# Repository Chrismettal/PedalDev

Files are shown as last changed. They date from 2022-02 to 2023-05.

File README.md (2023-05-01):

# PedalDev <!-- omit in toc -->





This is a convenient system for quickly creating stompboxes, as well as a collection of designs made with this system.

The design is split into two boards, a lower and an upper one. The lower PCB handles all of the I/O, switching, and power stuff, while the upper one focuses on the individual effect. The two boards plug together and fit neatly inside a commonly used Hammond 1590B. For each finished design there is also a PCB frontpanel so I don't have to deal with any actual design work and can just hide my designs behind technical looking stuff. The actual boards take full advantage of modern SMD components for optimal space usage.

All designs build up from the same template to allow rapid creation of new designs as well as saving time on recurring steps. There are even various protoboard variants of the upper PCB fitting the same template, to make boutique one-off designs more convenient and robust. For every design you will find the full KiCAD project including schematic and production files like **BOM, Gerbers and PCBA place files** in their respective project folders. (`/pcb/*`)

For easy mechanical manufacturing a 3D printable drilling template is provided. There is also a 3D printable design of the full stompbox similar to the 1590B with all ports "predrilled". A plastic case is not super recommended though and should only be used for quick testing. Conductive spray paint as shielding on the inside is also recommended when using the 3D printed case. (`/3d/*`)

Parts marked with ":construction:" are work in progress and not fully verified yet.

---

Individual boards, predrilled cases as well as kits will be stocked at Tindie!



**If you like my work please consider [supporting my caffeine addiction](https://github.com/Chrismettal#donations)!**

## Table of contents <!-- omit in toc -->

- [Specific Designs](#specific-designs)
  - [404 (:sheep: Ibanez Tubescreamer)](#404-sheep-ibanez-tubescreamer)
  - [YOU WHAT?! (:sheep: emma electronic PisdiYAUwot)](#you-what-sheep-emma-electronic-pisdiyauwot)
  - [:construction: TOP (:sheep: OKKO Dominator)](#construction-top-sheep-okko-dominator)
- [Common PCBs](#common-pcbs)
  - [Lower](#lower)
  - [:construction: Lower Smart](#construction-lower-smart)
- [Protoboards](#protoboards)
  - [Proto Simple](#proto-simple)
- [Designing your own effects](#designing-your-own-effects)
- [Building guide](#building-guide)
  - [Case](#case)
  - [Electronics](#electronics)
- [Sources](#sources)
- [Tools](#tools)
- [Donations](#donations)
- [License](#license)

## Specific Designs

While there aren't many specific designs right now, they will be created faster now that the system is proven working. There is a wide range of devices in the works, from high gain distortions over reverbs to new, experimental stuff.

### 404 (:sheep: Ibanez Tubescreamer)

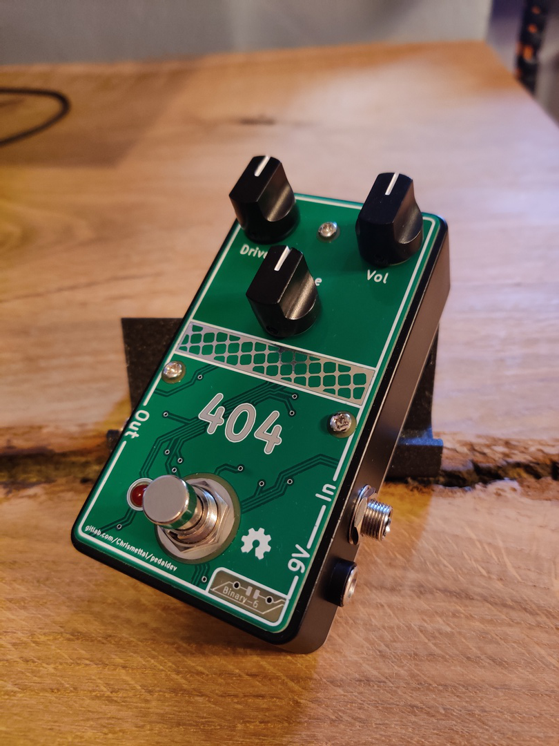
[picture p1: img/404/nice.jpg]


Based on the popular Tubescreamer this is obviously the first design to be done in this system.

Nothing crazy here, only `D1-3` feature a dual footprint to put in your favourite clipping diodes.

There are two jumpers that need to be set when building this board. `JP1` does not really do anything with the sound but chooses a filter to be sent to ground or to bias voltage as some schematics have it either way. `JP2` however allows choosing betweeen symmetrical or assymetrical clipping.

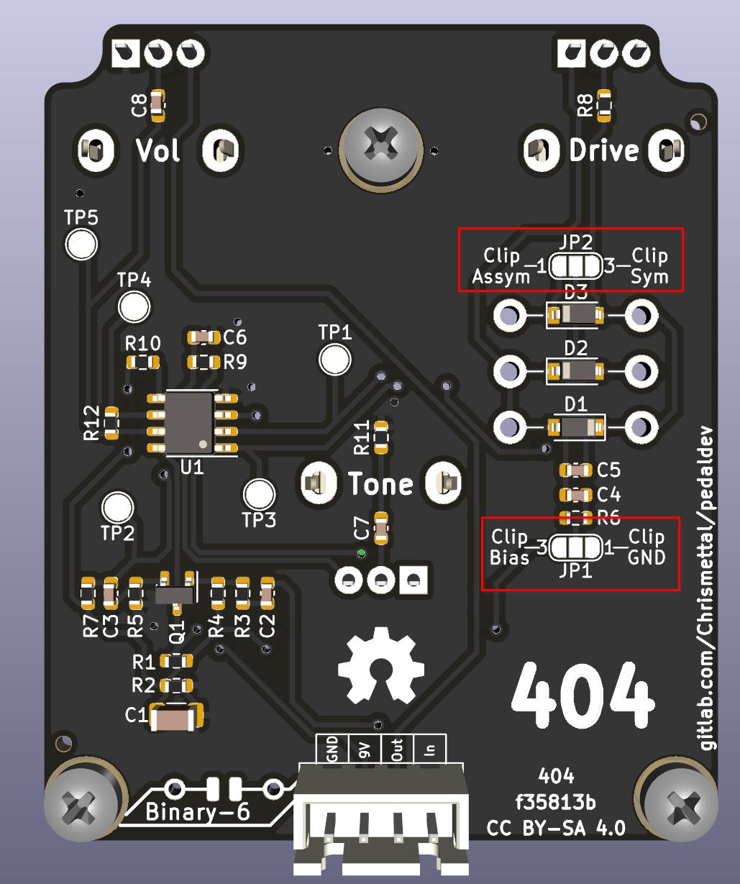
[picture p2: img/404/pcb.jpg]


### YOU WHAT?! (:sheep: emma electronic PisdiYAUwot)

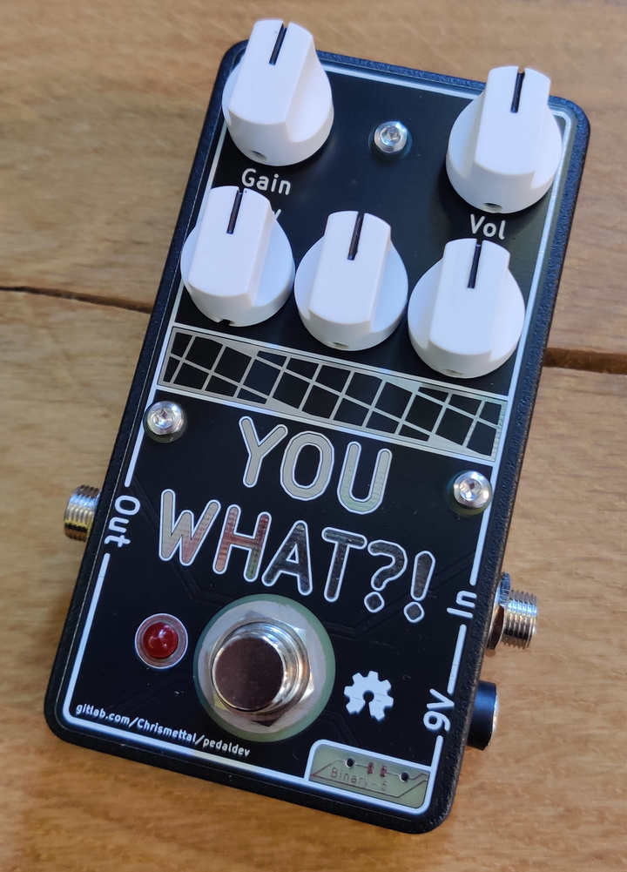
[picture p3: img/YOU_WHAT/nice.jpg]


Very cheap in parts but incredibly tight high gain distortion with lots of attack.

### :construction: TOP (:sheep: OKKO Dominator)

:construction: :construction: :construction: **Work in progress** :construction: :construction: :construction:

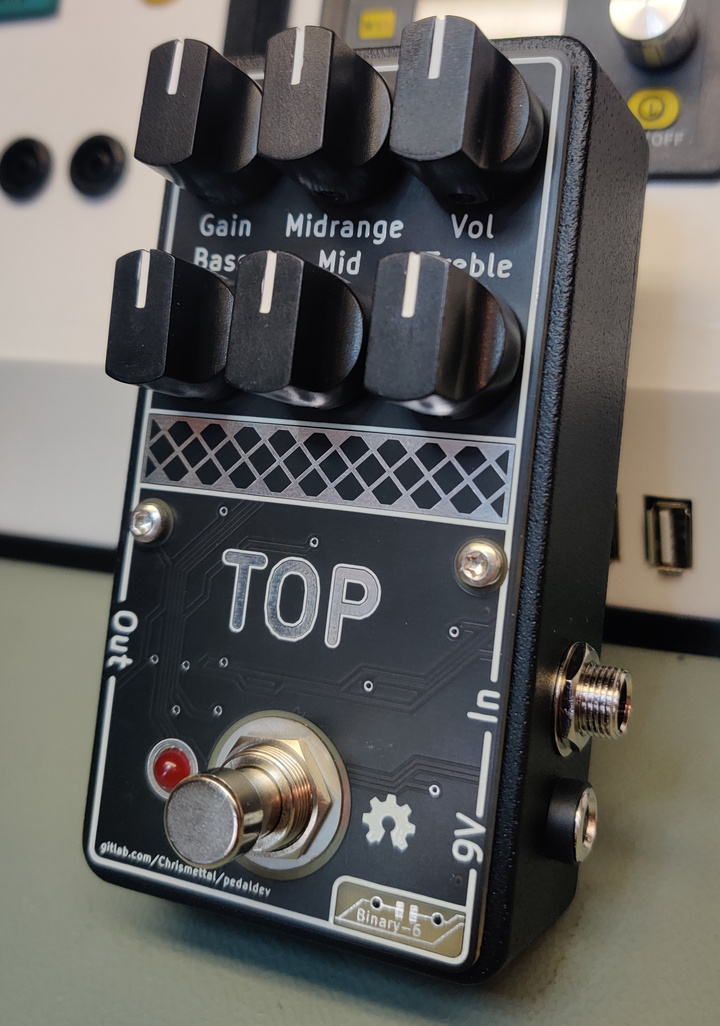
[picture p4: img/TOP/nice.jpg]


Based on schematic by Saruman [found here](https://www.freestompboxes.org/viewtopic.php?t=12031&hilit=c6).

First PCB version `f35813b` was broken is currently being debugged. 4 Pins on `TL074` were swapped, `ICL7660` does not work when `BOOST` mode is set (But **`ICL7660S`** does..), and input stage sounds super starved, more like a bassy fuzz than a distortion. Simulation seems to confirm this so confidence in schematic is low. Currently getting hold of an original Dominator for schematic comparison.

Two jumpers on board revision `f35813b` are for debugging the power stage around the `7660` but will probably be removed or clarified on the fixed revision

## Common PCBs

### Lower

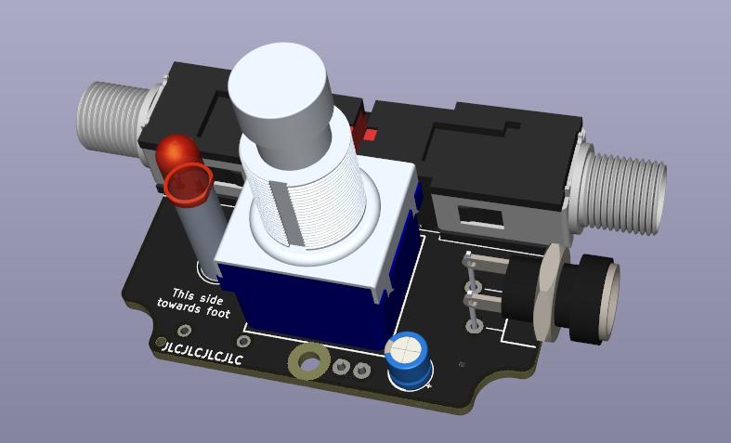
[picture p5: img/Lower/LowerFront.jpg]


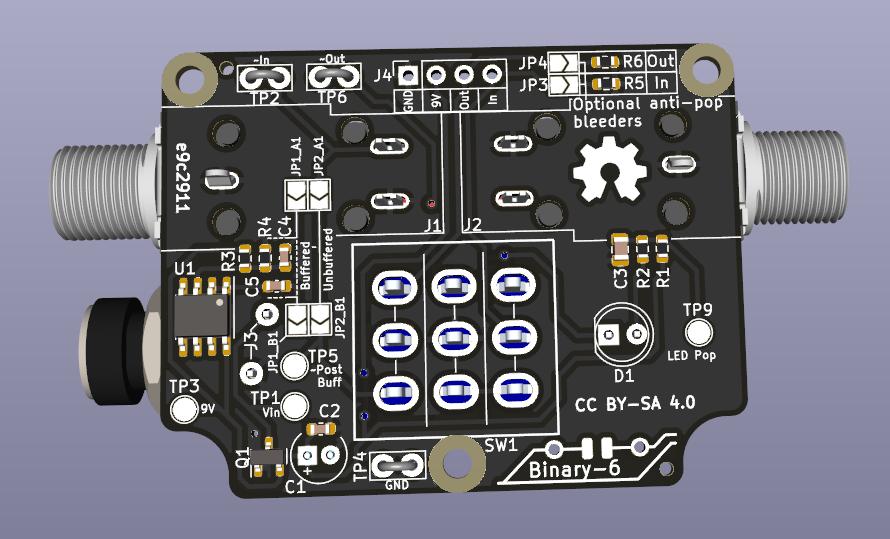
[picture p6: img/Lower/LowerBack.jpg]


The lower PCB consists of the bypass footswitch with a status LED, input and output jacks as well as power input, filtering and FET based reverse polarity protection.

The Input/Output jacks are called `PJ-602B`. These are not available via LCSC sadly, but can be found all over Aliexpress. 

Additionally an optional TL07X based buffer can be enabled via two jumpers. This was only added because the PCB had enough room for it and it can save room on the pedalboard instead of adding a separate buffer box. The buffer parts do NOT NEED to be populated if you intend never to use them. **Either `JP1_A1` and `JP1_B1` or `JP2_A1` and `JP2_B1` need to be set for signal to be passed through**.

The LED is driven through a simple "anti pop" filter and two optional anti-pop bleeders can be enabled via `JP3` and `JP4` to bleed any input/output caps on the connected upper board if neccessary.

Test hooks and pads are sprinkled on interesting signals for effect development and debugging.

> :bulb: Hint: 
> 
> While this system is intended to be used with one lower PCB and one upper PCB fitting together, it might be convenient to just use the lower PCB even if you do not intend to use an actual effect from this system. Doing so greatly reduces the amount of free form wiring and frees up some space on your actual effect PCB.

### :construction: Lower Smart

:construction: :construction: :construction: **Work in progress** :construction: :construction: :construction:

Same as `Lower`, but instead of a true bypass 3PDT Switch it features a microcontroller to turn your effect on and off either in momentary or latching mode. To show the mode it's currently on, it uses a bicolor LED.

On initial bootup, the device will be in latching mode. Pressing the button will toggle the effect on and off. The :construction: colored LED will be on as long as the effect is on in toggle mode. 
Holding the button down for 9 seconds, both LEDs will start blinking, signaling that a mode change is imminent. Holding the button for one more second, the device will switch into momentary mode.
In momentary mode, the effect will only be on while the button is held. While the effect is on, a :construction: colored LED will be on in momentary mode.
Switching back to toggle mode works the same way, by holding down the button long enough.

## Protoboards

### Proto Simple

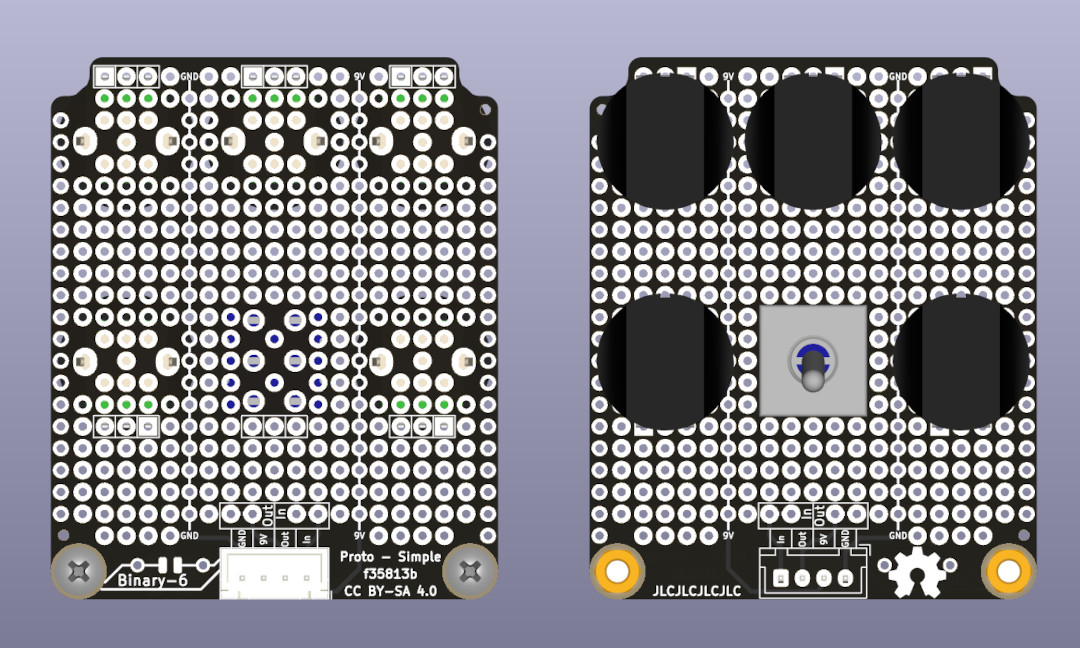
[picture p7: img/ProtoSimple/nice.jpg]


This is a simple protoboard to use as an "upper" board, allowing for up to 6 pots, or 5 pots with one DPDT print switch.
It features 9V and GND power rails straight through the design to allow for easy power distribution

While it does not allow for the density of SMD components it can certainly fit a lot of designs.

## Designing your own effects

I would love to merge your designs using this system into this repo!

To design your own effect PCB, create a copy of the `UpperRaw` KiCAD project for the actual effect, and `FrontRaw` for a PCB frontpanel design. `UpperRaw` includes a collection of frequently used parts in the schematic, set up with LCSC part numbers etc. It would be great if you add LCSC part numbers to all parts used in your design as well. After merging I will recreate the production files to the same parameters as the already created designs so don't worry about that.

---

## Building guide

As the system tries to use the little space in the 1590B as efficient as possible, the actual build can be quite tight. There is a set order of steps that should be taken to make the build as quick and easy as possible.

The whole system is designed so the PCBs can be ordered from JLCPCB mostly populated, so only very little hand soldering is involved. If you order the boards finished you will mostly have to solder only the through hole components, but for some rare components that JLCPCB doesn't populate, it might be neccessary to solder some SMD components manually. SMD components go down to `0603` for passives, and `SOIC-*` / `SOT-*` for actives, which is still hand solderable without too much trouble. A hot air solder station is highly recommended though.

<details>
  <summary markdown="span">Building guide, click to expand</summary>

### Case

If you have access to a 3D printer (or to my [Tindie Shop](https://www.tindie.com/stores/binary-6/)), there is a printable drill guide available. Otherwise, there will be a techdraw sheet with all the dimensions. At the [shop](https://www.tindie.com/stores/binary-6/) you will also find predrilled, black cases directly manufactured by Hammond.

All models are compatible with the same drill layout. Holes not required for a specific board will be hidden by the front plate, so the fully stacked 6 controls variant works for every model.

1. Put the case in the drill guide and use a center punch to mark out all the holes to be drilled

2. Pre-drill all marked holes with a `3mm drill bit` (The smallest size used on the device)

3. Drill out all the holes to the sizes marked on the drill guide. Note that the holes are all 0.5mm - 1mm larger than they need to be to make alignment of the frontpanel easier

4. If you want to paint the case, this would be the step to do it. I clean the case with rubbing alcohol, prime and paint, while only focusing on the sides of the case as I will hide the top underneath the frontpanels.

### Electronics

1. Some boards require several components to be mounted manually (Check their individual [documentation](#specific-designs)). These will include through hole parts or not easily available active parts for example. In this case, the OpAmp and input stage transistors, as well as connectors need to be placed manually. Note that the pots and switches are NOT placed at this stage!

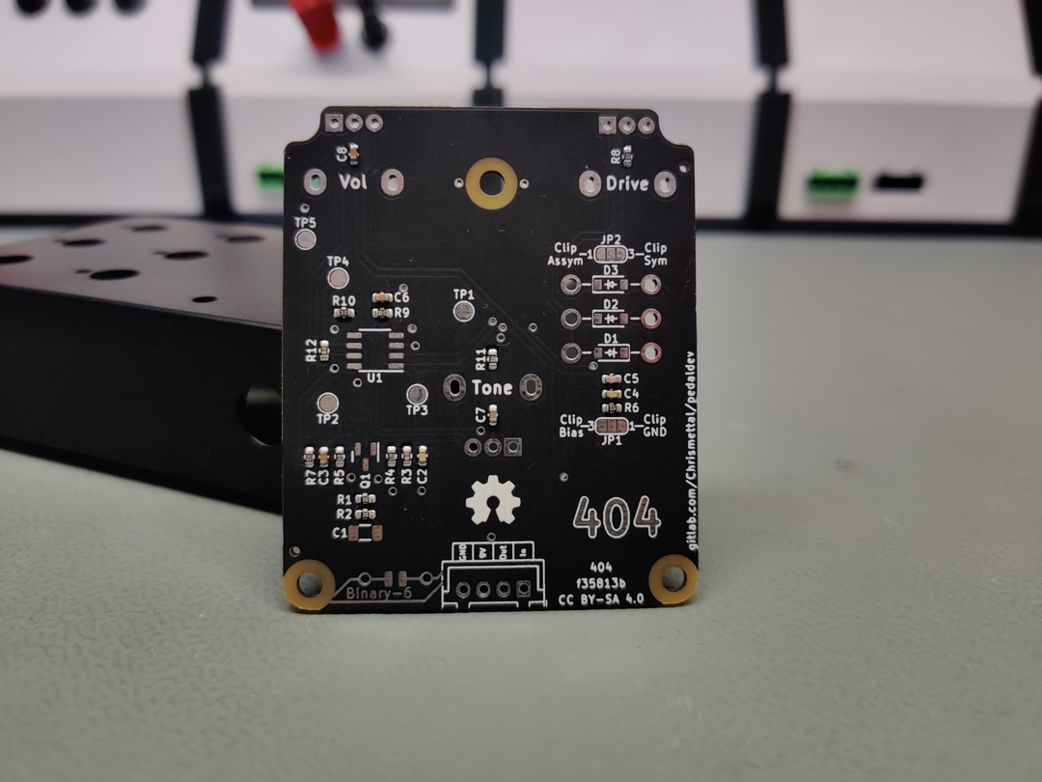
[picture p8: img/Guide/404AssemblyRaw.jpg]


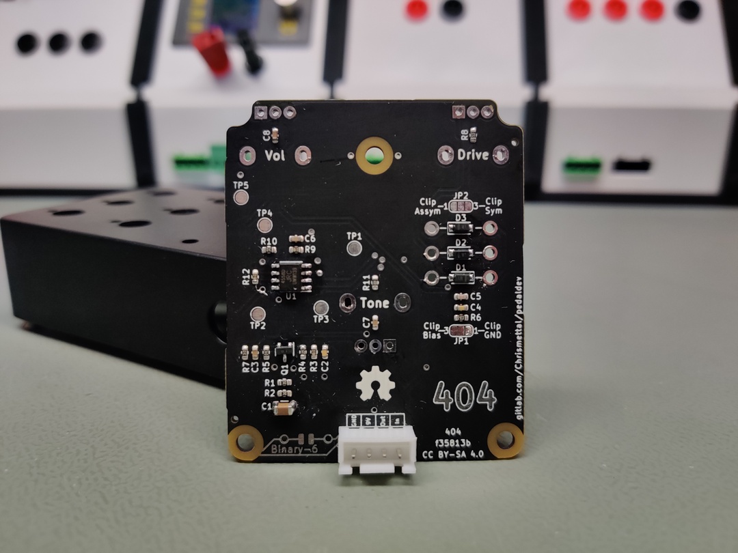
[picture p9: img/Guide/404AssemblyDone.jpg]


---

2. The lower PCB also requires some assembly, namely attaching the LED with its spacer and soldering on the board-to-board connector wire. Make sure to set **either `JP1_A1` and `JP1_B1` or `JP2_A1` and `JP2_B1` need to be set for signal to be passed through**.

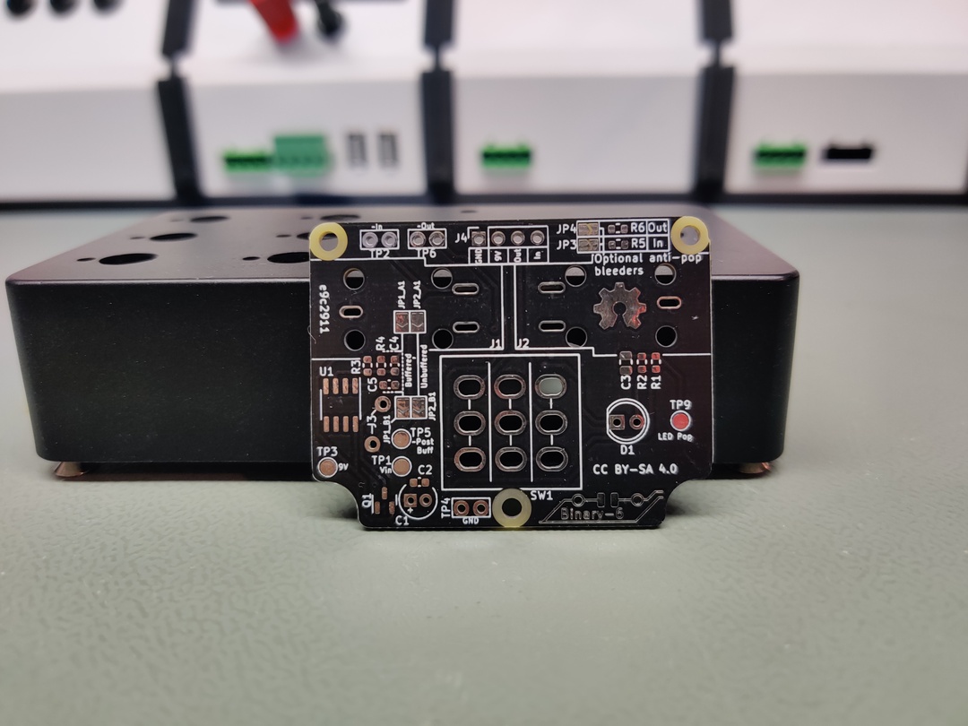
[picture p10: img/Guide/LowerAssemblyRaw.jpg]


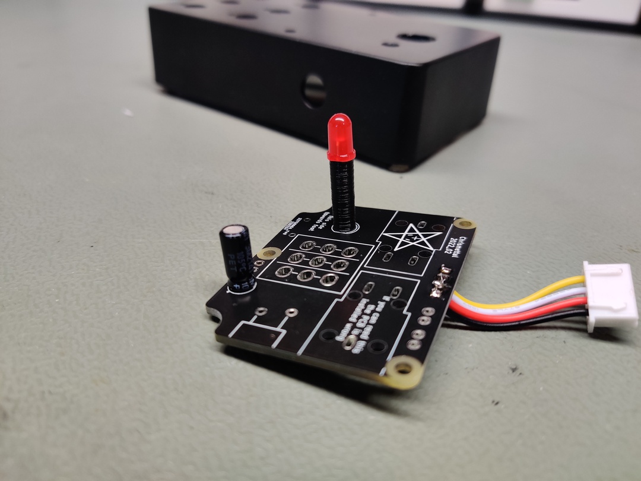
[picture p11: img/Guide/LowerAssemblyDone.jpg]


---

3. On most boards you will also find some configuration jumpers to be set. These include for example the `Buffered - Unbuffered` jumpers for the [Lower](#lower) PCB. Note the individual boards [documentation](#specific-designs).

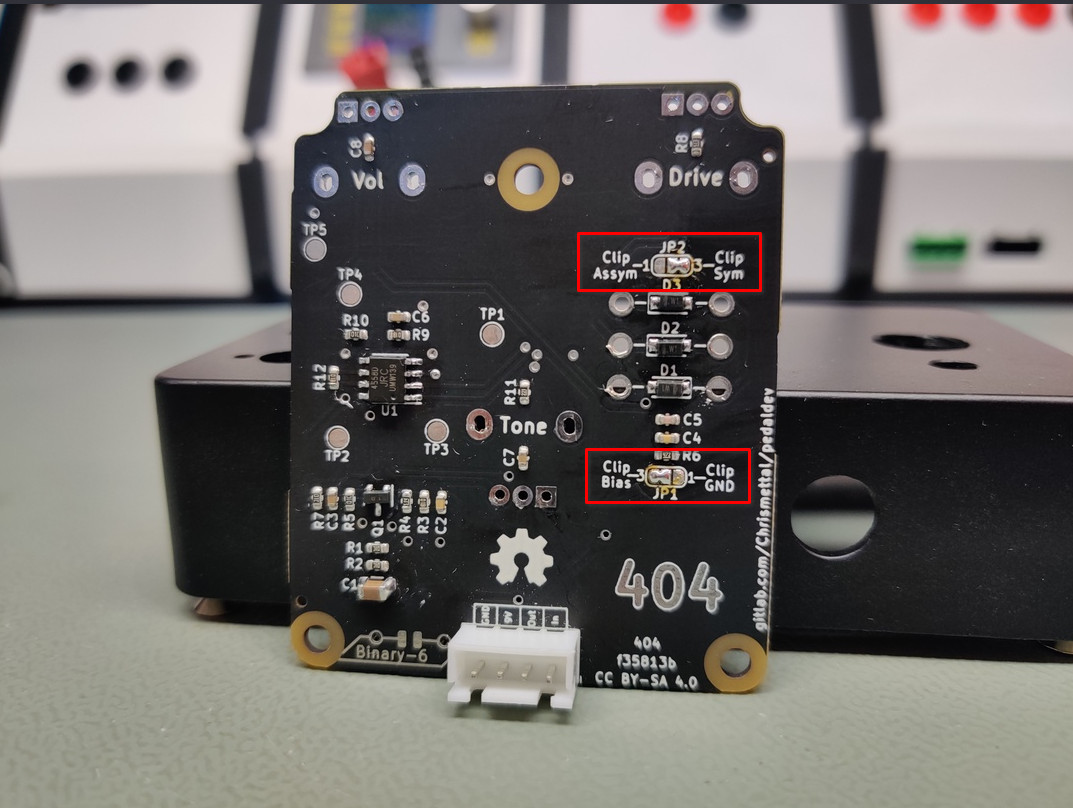
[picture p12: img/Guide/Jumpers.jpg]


---

4. Attach the 10mm spacers to upper board, facing the "Towards foot" side. No washers required.

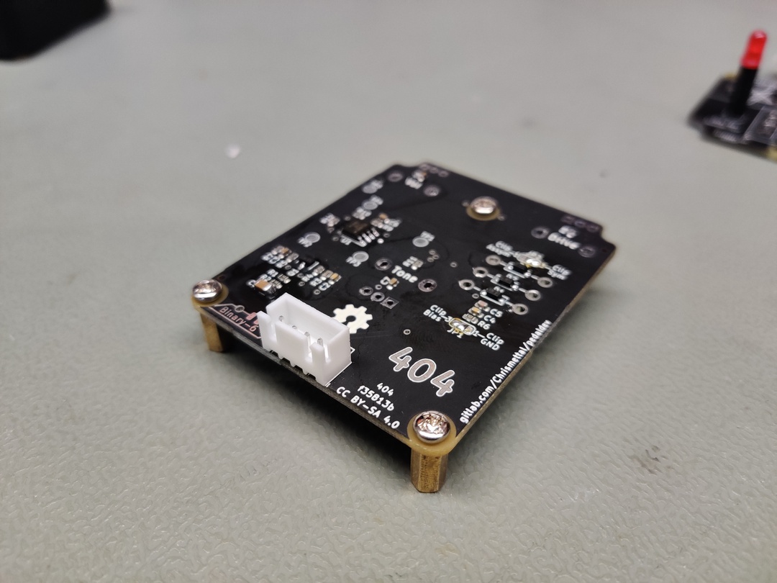
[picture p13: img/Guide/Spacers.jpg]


---

5. Prepare the power jack by attaching two solid wires to the jack as shown. Make sure to keep them straight for easier insertion later

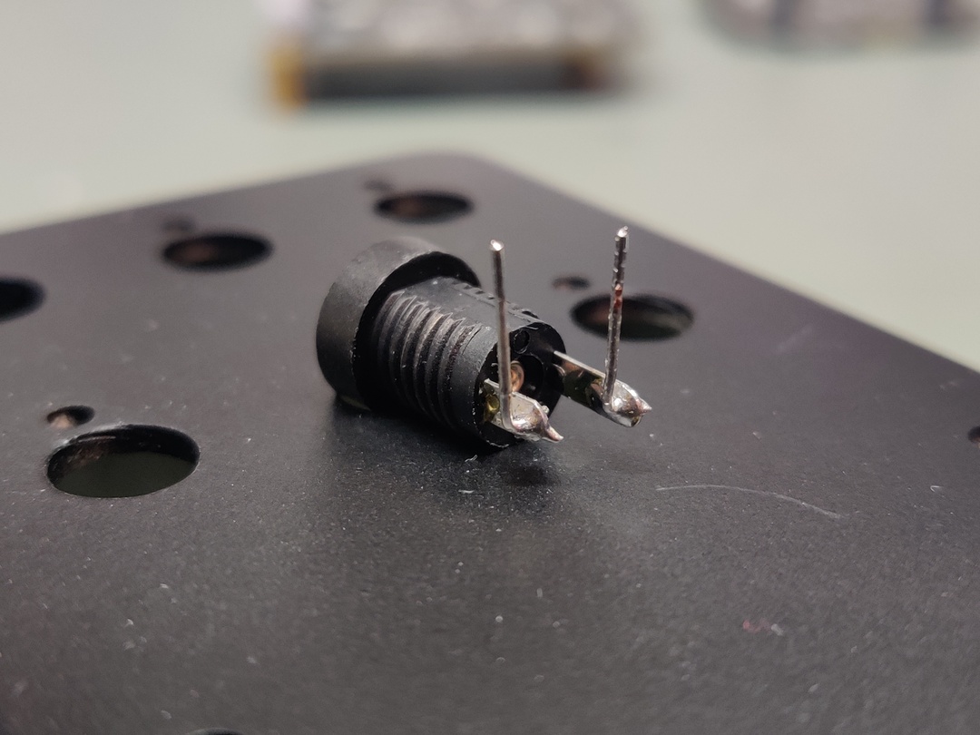
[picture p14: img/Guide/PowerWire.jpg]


---

6. Mount all jacks, pots and switches to the case, optionally applying the FrontPanel. Do the input/output jacks first, as you will need to have some space to tilt the jacks while inserting them both into the case. They will go in VERY tight, but they will fit. For the power jack, make sure that the pins face upwards. Make sure to keep a single nut on the footswitch to have the correct spacing.

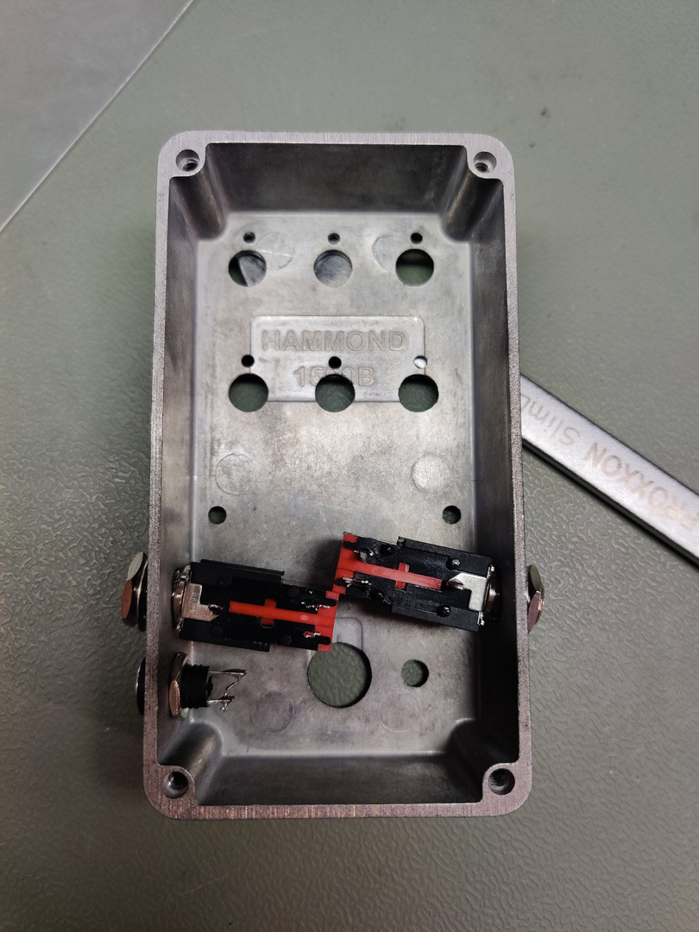
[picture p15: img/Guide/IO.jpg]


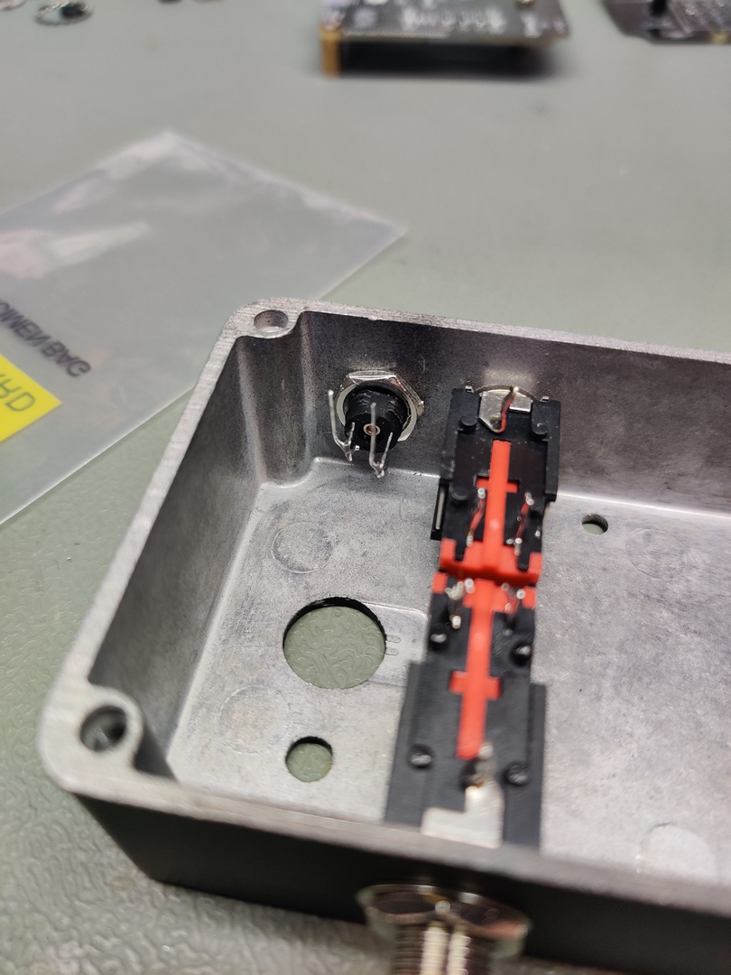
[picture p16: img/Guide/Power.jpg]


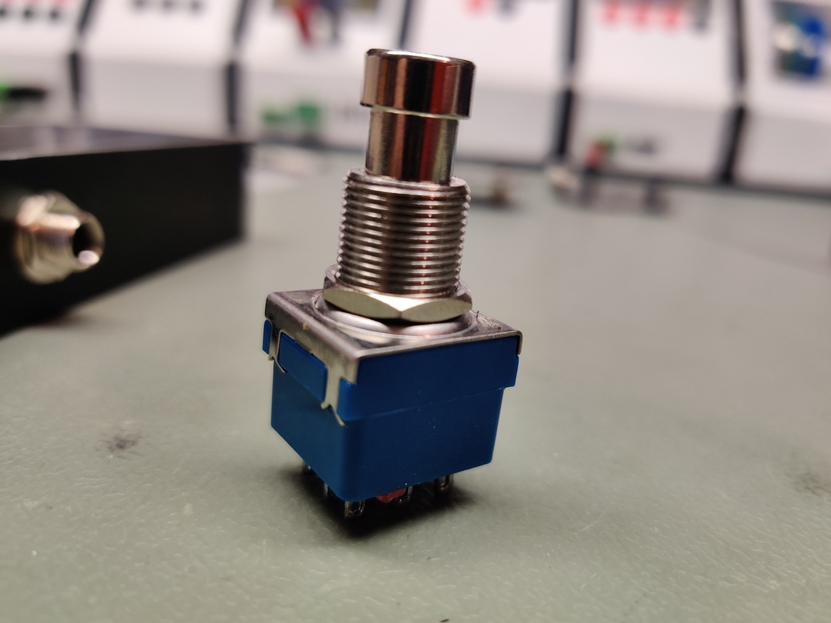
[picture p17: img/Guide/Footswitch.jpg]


---

7. Insert the pots, making sure to put each pot the correct hole for your design. Check out the silkscreen on your upper PCB for that. The nut probably won't have much flesh to grip onto so only handtighten them, or leave them out if necessary. The board will be held by screws later so it's no big deal. I like to straighten the potpins after mounting so I have  an easier time inserting the PCB in the next step. 

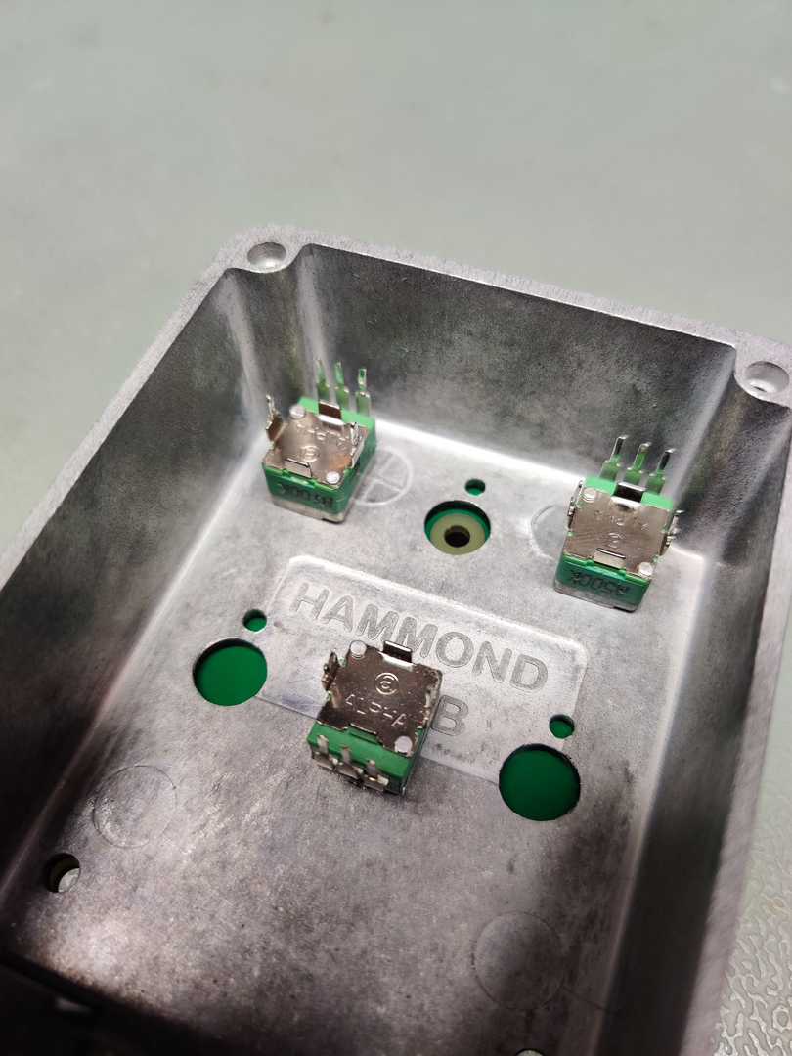
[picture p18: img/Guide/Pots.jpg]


---

8. If your board does not use the middle upper pot, place a spacer inside the hole where a screw will go

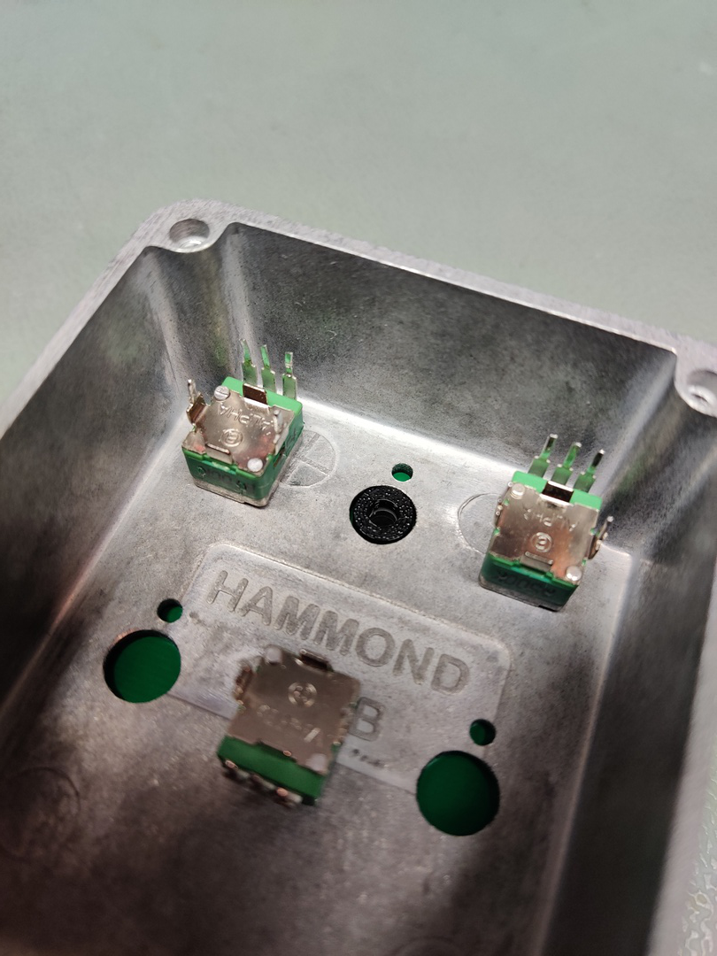
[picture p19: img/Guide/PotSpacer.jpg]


---

9.  Place the upper board on top of the controls. Might be a bit tricky to align all the holes, but it can be made a bit easier by loosening all the controls screws. While it is also possible to first solder on all the controls, slight misalignments in height will lead to mechanical stress on the board when screwing the controls down later. Soldering it after mounting will ensure a mechanically unstressed board and still allow unmounting the board later by unscrewing the controls.

---

10. Secure the PCB with screws from the front, Screw down all controls tightly and after makind sure your pots all spin freely (not crooked), then solder all controls to the board.

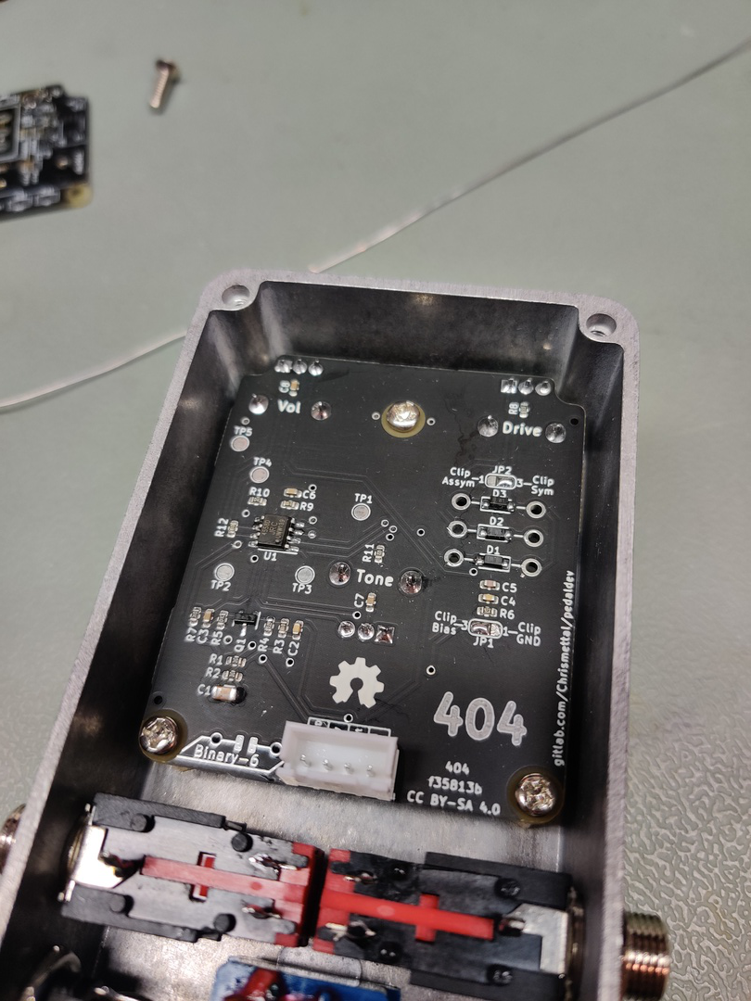
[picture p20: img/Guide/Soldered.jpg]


---

11. Place the lower board on top of the I/O

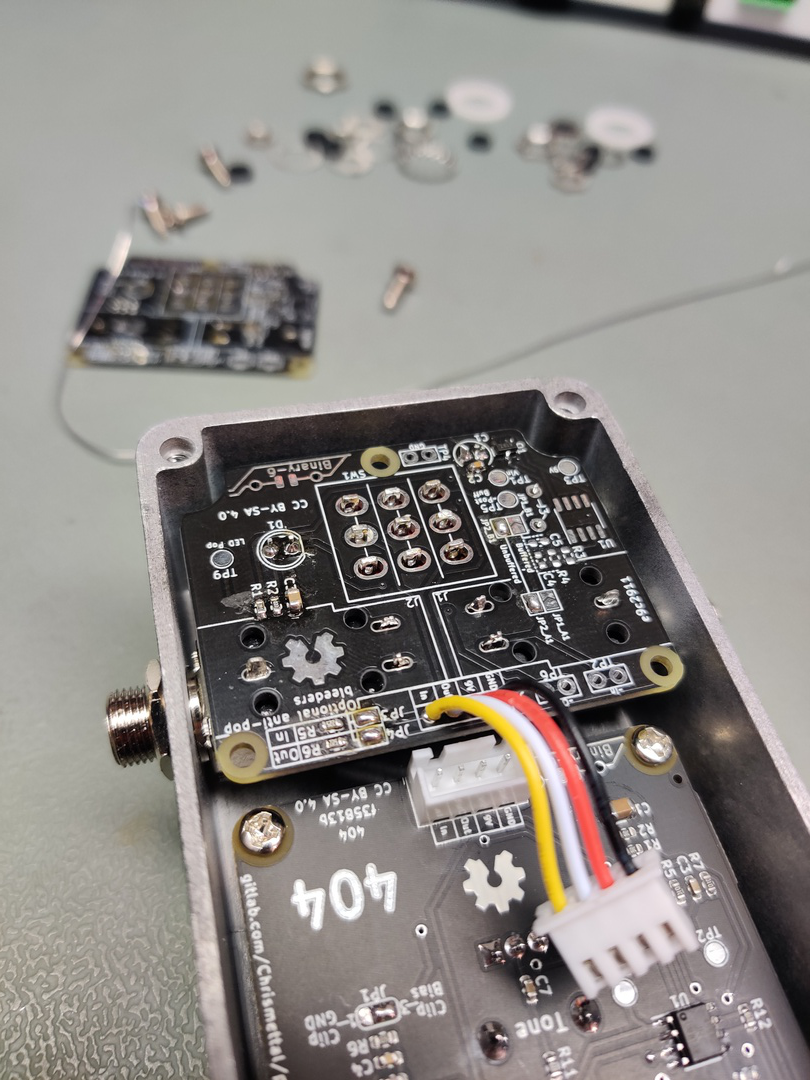
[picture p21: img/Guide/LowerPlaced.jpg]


---

12.  Solder down the lower PCB. Note that this board will NOT be easily removeable without unsoldering the controls again!

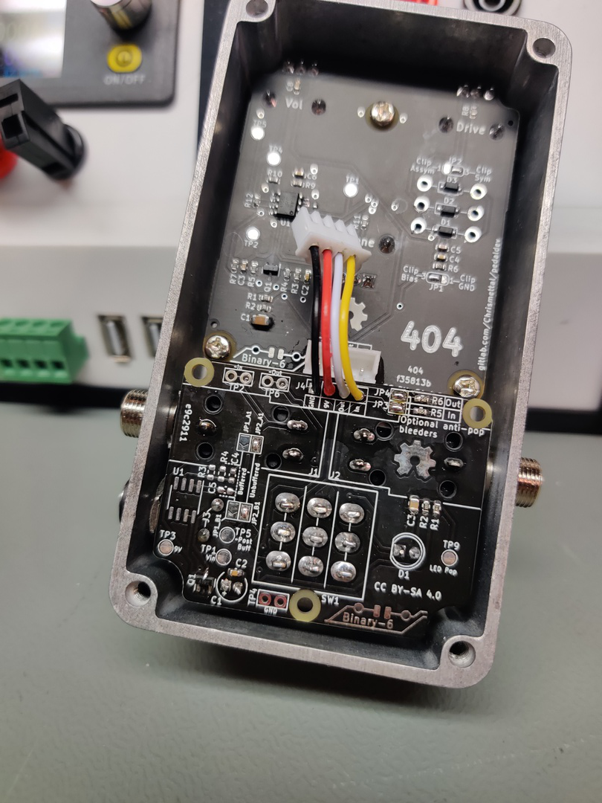
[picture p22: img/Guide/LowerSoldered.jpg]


---

13.  Plug in the board-to-board connector.

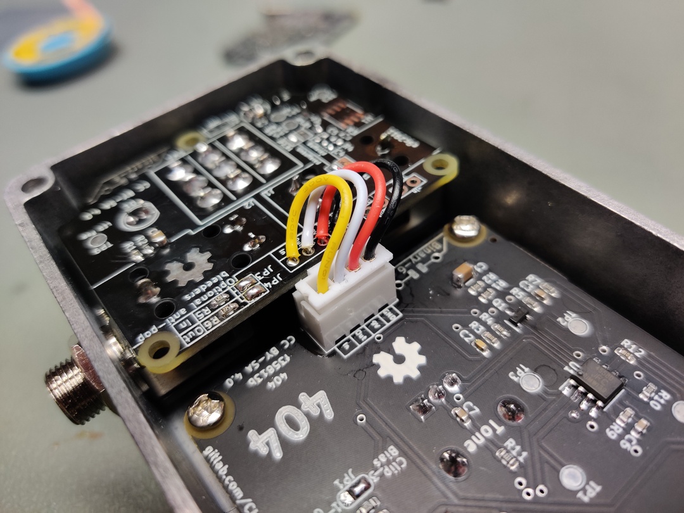
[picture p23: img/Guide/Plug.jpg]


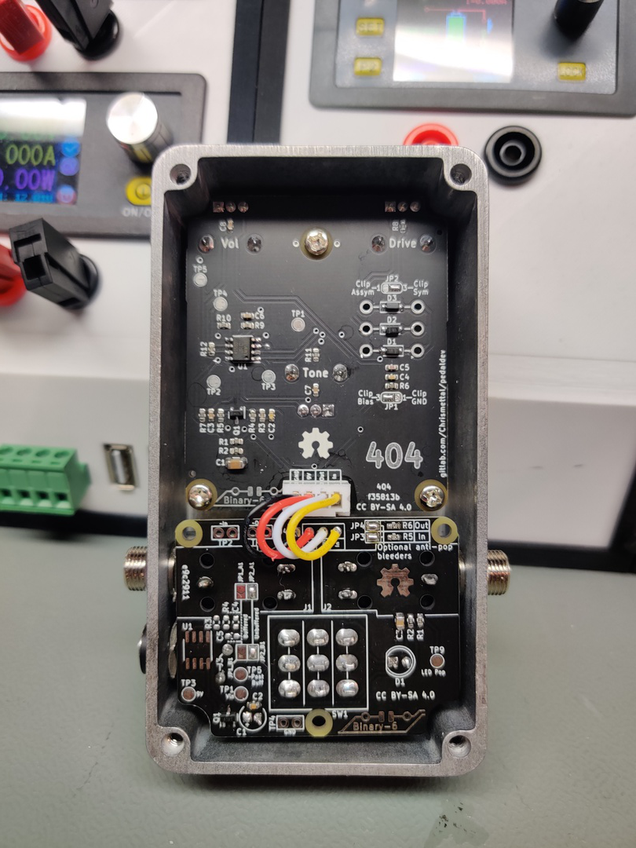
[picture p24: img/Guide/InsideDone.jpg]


---

14.  Screw on the bottom plate and mount your pot knobs.

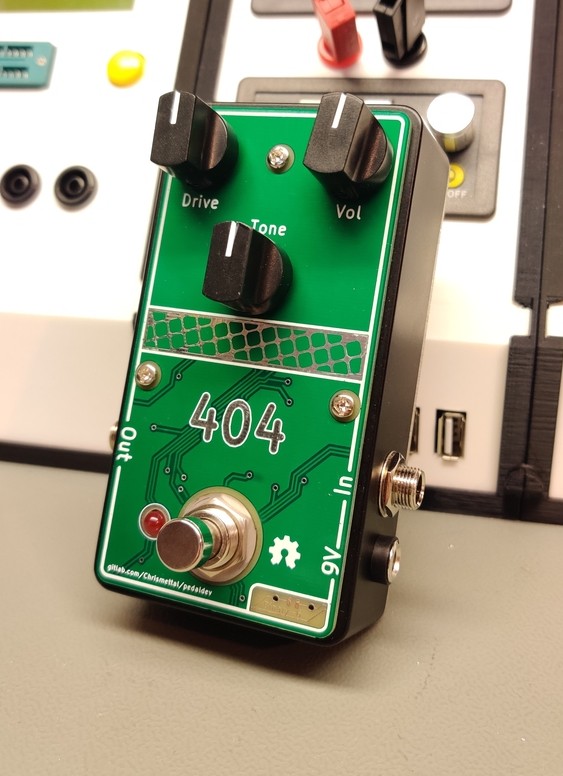
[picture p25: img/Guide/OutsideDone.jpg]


---

15. Done!

</details>

## Sources

The following 3D models were used for the simulation renders in KiCAD and FreeCAD. Please check their respective licenses if you intend to reuse them.

Any models that are **not** mentioned here were created by me for this project and are subject to the same [license](#license) as the whole repo.

| File | Link |
| --- | --- |
| Hammond 1590B | https://www.hammfg.com/part/1590B |
| PJ-602B Audio jacks | https://github.com/afedorov3/3DModels |
| Footswitch_3PDT | https://grabcad.com/library/3pdt-switch-1 |
| 9mm potentiometers  | https://grabcad.com/library/alpha-rd901f-40-15r1-1 |
| DC barrel jack | https://grabcad.com/library/5-5mm-panel-mount-dc-jack-1 |
| LED 5mm | https://grabcad.com/library/led-5mm-1#! |

## Tools

- PCBs: [KiCAD 6](https://www.kicad.org/)
- 3D CAD: [FreeCAD 0.20](https://www.freecadweb.org/)
- Source code: [PlatformIO](https://platformio.org/)

## Donations

**If you like my work please consider [supporting my caffeine addiction](https://github.com/Chrismettal#donations)!**

## License

 <br />This work is licensed under a <a rel="license" href="http://creativecommons.org/licenses/by-sa/4.0/">Creative Commons Attribution-ShareAlike 4.0 International License</a>.

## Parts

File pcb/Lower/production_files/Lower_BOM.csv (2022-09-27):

Comment | Designator | Footprint | LCSC
100uF | C1 | Capacitor_THT:CP_Radial_D5.0mm_P2.00mm | C108360
220nF | C2,C4,C5 | Capacitor_SMD:C_0603_1608Metric | C21120
10uF | C3 | Capacitor_SMD:C_0805_2012Metric | C15850
LED | D1 | LED_THT:LED_D5.0mm | C417347
AudioJack3 | J1,J2 | MeineBib:Audio_Jack_PJ-602B
Barrel_Jack | J3 | MeineBib:DC_Barrel_Jack_Thinline_Wired_Standing
AO3401A | Q1 | Package_TO_SOT_SMD:SOT-23 | C347476
390R | R1 | Resistor_SMD:R_0603_1608Metric
2k2 | R2 | Resistor_SMD:R_0603_1608Metric
1M | R3,R4 | Resistor_SMD:R_0603_1608Metric
2M2 | R5,R6 | Resistor_SMD:R_0603_1608Metric
SW_Push_3PDT | SW1 | MeineBib:Footswitch_3PDT
TL072 | U1 | Package_SO:SOIC-8_3.9x4.9mm_P1.27mm | C6961

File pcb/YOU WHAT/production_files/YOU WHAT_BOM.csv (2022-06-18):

Comment | Designator | Footprint | LCSC
1nF | C10,C12,C14 | Capacitor_SMD:C_0603_1608Metric | C1588
22nF | C13,C15 | Capacitor_SMD:C_0603_1608Metric | C21122
10nF | C16,C19 | Capacitor_SMD:C_0603_1608Metric | C57112
100uF | C2 | Capacitor_SMD:CP_Elec_6.3x5.3 | C134723
47nF | C4,C8,C9,C17,C18 | Capacitor_SMD:C_0603_1608Metric | C1622
47pF | C6,C20,C21,C22,C23 | Capacitor_SMD:C_0603_1608Metric | C1671
220nF | C7,C11 | Capacitor_SMD:C_0603_1608Metric | C21120
Conn_01x04 | J1 | Connector_JST:JST_XH_B4B-XH-A_1x04_P2.50mm_Vertical | C144395
BC849C | Q1 | Package_TO_SOT_SMD:SOT-23 | C334244
10k | R1,R3,R7,R9,R11,R14,R21 | Resistor_SMD:R_0603_1608Metric | C25804
1M | R13,R22 | Resistor_SMD:R_0603_1608Metric | C22935
10M | R16 | Resistor_SMD:R_0603_1608Metric | C7250
47k | R19 | Resistor_SMD:R_0603_1608Metric | C25819
1k | R20 | Resistor_SMD:R_0603_1608Metric | C21190
4k7 | R4 | Resistor_SMD:R_0603_1608Metric | C23162
220k | R6,R18 | Resistor_SMD:R_0603_1608Metric | C22961
27k | R8,R12,R15,R17 | Resistor_SMD:R_0603_1608Metric | C22967
500K Lin | RV1,RV3 | MeineBib:Potentiometer_Alpha_RD901F-40-00D_Single_Vertical
500K Log | RV4 | MeineBib:Potentiometer_Alpha_RD901F-40-00D_Single_Vertical
10K Lin | RV5 | MeineBib:Potentiometer_Alpha_RD901F-40-00D_Single_Vertical
100K Lin | RV6 | MeineBib:Potentiometer_Alpha_RD901F-40-00D_Single_Vertical
HEF4069UB | U1 | Package_SO:SOIC-14_3.9x8.7mm_P1.27mm | C6739

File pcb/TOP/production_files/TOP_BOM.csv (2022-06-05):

DEPRECATED
Comment | Designator | Footprint | LCSC
10uF | C1 | Capacitor_SMD:CP_Elec_4x5.4 | C445047
100pF | C11 | Capacitor_SMD:C_0603_1608Metric | C14858
100nF | C12 | Capacitor_SMD:C_0603_1608Metric | C14663
47nF | C17 | Capacitor_SMD:C_0603_1608Metric | C1622
1nF | C18,C27,C29 | Capacitor_SMD:C_0603_1608Metric | C1588
470nF | C19,C28 | Capacitor_SMD:C_0603_1608Metric | C1623
10uF | C2,C3,C9,C13,C14,C20,C22 | Capacitor_SMD:C_0805_2012Metric | C15850
68nF | C26 | Capacitor_SMD:C_0603_1608Metric | C31658
100uF | C30 | Capacitor_SMD:CP_Elec_6.3x5.4_Nichicon | C111600
22nF | C4,C21,C23,C24 | Capacitor_SMD:C_0603_1608Metric | C21122
470pF | C5 | Capacitor_SMD:C_0603_1608Metric | C1620
2.2uF | C6 | Capacitor_SMD:C_0603_1608Metric | C23630
10nF | C7,C15 | Capacitor_SMD:C_0805_2012Metric | C1710
220nF | C8,C10,C16,C25 | Capacitor_SMD:C_0603_1608Metric | C21120
1N4004 | D1,D2 | Diode_SMD:D_SMA | C433394
Conn_01x04 | J1 | Connector_JST:JST_XH_B4B-XH-A_1x04_P2.50mm_Vertical | C144395
BF545A | Q1,Q2 | Package_TO_SOT_SMD:SOT-23
51R | R1 | Resistor_SMD:R_0603_1608Metric | C23197
2K2 | R10,R28 | Resistor_SMD:R_0603_1608Metric | C4190
22K | R11 | Resistor_SMD:R_0603_1608Metric | C31850
100K | R12 | Resistor_SMD:R_0603_1608Metric | C25803
1K | R13,R23,R32 | Resistor_SMD:R_0603_1608Metric | C21190
7K5 | R14,R29 | Resistor_SMD:R_0603_1608Metric | C23234
15K | R17 | Resistor_SMD:R_0603_1608Metric | C22809
47K | R19,R20,R21 | Resistor_SMD:R_0603_1608Metric | C25819
1M | R2,R4,R24 | Resistor_SMD:R_0603_1608Metric | C22935
39K | R22 | Resistor_SMD:R_0603_1608Metric | C23153
10K | R3,R5,R6,R9,R15,R16,R18,R25,R26,R27,R31,R33,R36 | Resistor_SMD:R_0603_1608Metric | C25804
470R | R30 | Resistor_SMD:R_0603_1608Metric | C23179
330R | R34 | Resistor_SMD:R_0603_1608Metric | C23138
470K | R7,R8,R35 | Resistor_SMD:R_0603_1608Metric | C23178
100K Lin | RV1 | MeineBib:Potentiometer_Alpha_RD901F-40-00D_Single_Vertical
1M lin | RV2 | MeineBib:Potentiometer_Alpha_RD901F-40-00D_Single_Vertical
100K Log | RV3 | MeineBib:Potentiometer_Alpha_RD901F-40-00D_Single_Vertical
10k Lin | RV4 | MeineBib:Potentiometer_Alpha_RD901F-40-00D_Single_Vertical
25k Lin | RV5,RV6 | MeineBib:Potentiometer_Alpha_RD901F-40-00D_Single_Vertical
ICL7660 | U1 | Package_SO:SOP-8_3.9x4.9mm_P1.27mm | C356724
L78L15_SOT89 | U2 | Package_TO_SOT_SMD:SOT-89-3 | C411742
TL074 | U3 | Package_SO:SOIC-14_3.9x8.7mm_P1.27mm | C6963
OPA2604 | U4 | Package_SO:SOIC-8_3.9x4.9mm_P1.27mm | C30608

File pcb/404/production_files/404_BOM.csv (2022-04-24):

Comment | Designator | Footprint | LCSC
22uF | C1 | Capacitor_SMD:C_1206_3216Metric | C12891
47n | C2,C4 | Capacitor_SMD:C_0603_1608Metric | C1622
1uF | C3,C8 | Capacitor_SMD:C_0603_1608Metric | C15849
47pF | C5 | Capacitor_SMD:C_0603_1608Metric | C1671
220nF | C6,C7 | Capacitor_SMD:C_0603_1608Metric | C21120
1N4148W | D1,D2,D3 | MeineBib:D_SOD-123+THT | C81598
Conn_01x04 | J1 | Connector_JST:JST_XH_B4B-XH-A_1x04_P2.50mm_Vertical | C144395
BC846 | Q1 | Package_TO_SOT_SMD:SOT-23 | C87062
10K | R1,R2,R5,R7,R10 | Resistor_SMD:R_0603_1608Metric | C25804
220R | R11 | Resistor_SMD:R_0603_1608Metric | C22962
1K | R3,R9,R12 | Resistor_SMD:R_0603_1608Metric | C21190
510K | R4 | Resistor_SMD:R_0603_1608Metric | C23192
4K7 | R6 | Resistor_SMD:R_0603_1608Metric | C23162
51K | R8 | Resistor_SMD:R_0603_1608Metric | C23196
500K | RV1 | Potentiometer_THT:Potentiometer_Alpha_RD901F-40-00D_Single_Vertical
20k | RV2 | Potentiometer_THT:Potentiometer_Alpha_RD901F-40-00D_Single_Vertical
100K | RV3 | Potentiometer_THT:Potentiometer_Alpha_RD901F-40-00D_Single_Vertical
RC4558 | U1 | Package_SO:SO-8_3.9x4.9mm_P1.27mm | C406864

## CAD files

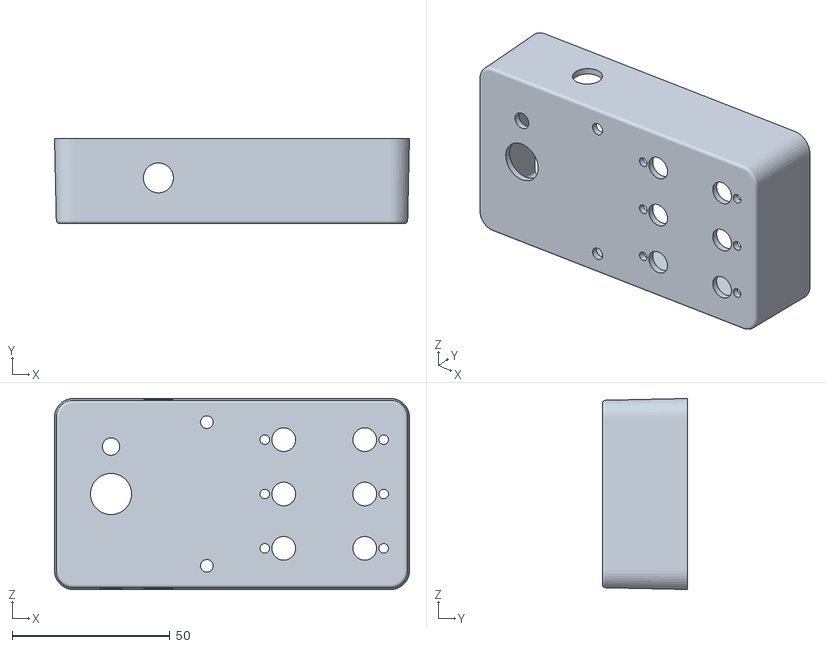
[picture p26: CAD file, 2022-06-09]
3d/BaseRaw/Case_Printable_ce0ce63.stl
112.4 x 27.0 x 60.5

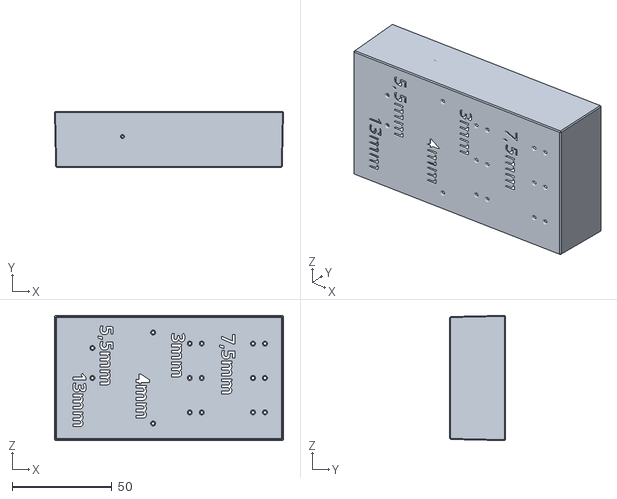
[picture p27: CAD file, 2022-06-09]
3d/BaseRaw/DrillGuide_Printable_ce0ce63.stl
114.6 x 28.0 x 62.7

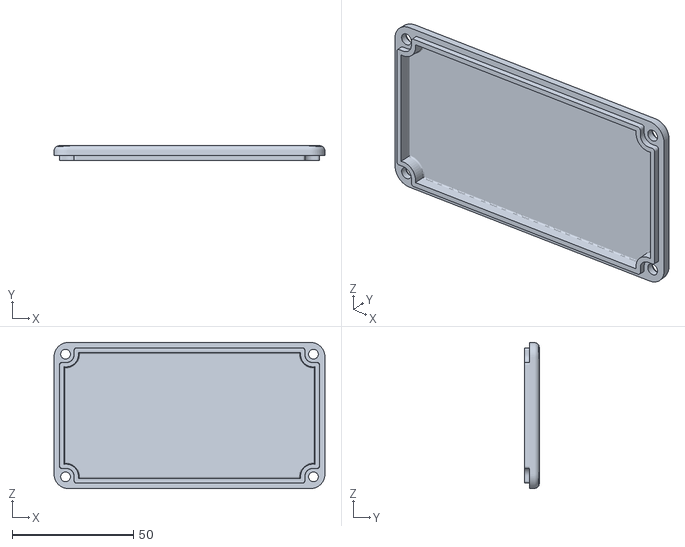
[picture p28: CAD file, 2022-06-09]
3d/BaseRaw/Lid_Printable_ce0ce63.stl
111.6 x 6.00 x 60.2

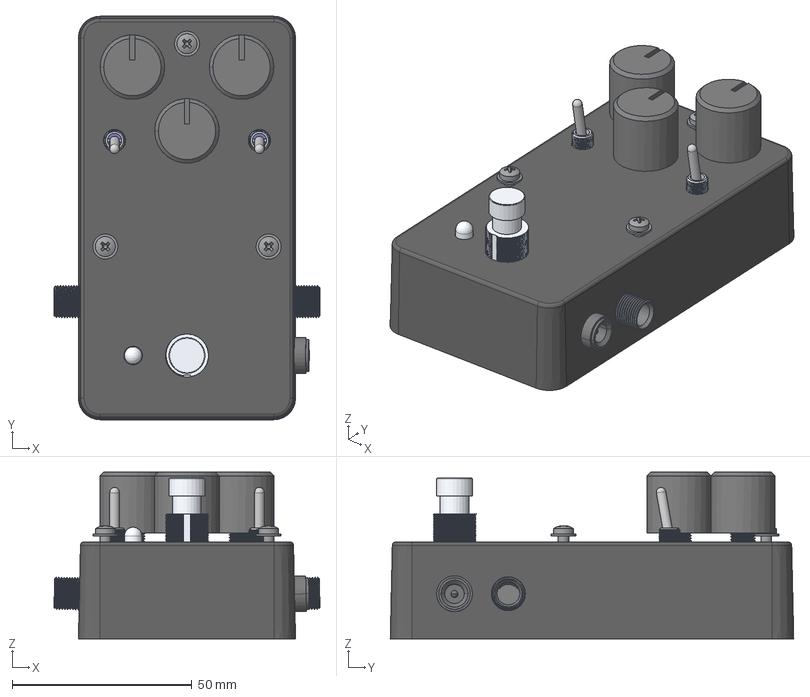
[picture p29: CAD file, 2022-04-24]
3d/BaseRaw/BaseRaw.FCStd
74.1 x 112.4 x 46.4 mm
Case
M3-Washer
M3-Washer009
M3x8-Screw009
M3x8-Screw
M3-Washer010
M3x8-Screw010
Pcb_d174
MK2_M3x6-Screw_4be4b4658190 x 3
MK2_M3x5x10-Spacer_4be4b4658190[2] x 3
J1_JST_B4B_XH_A_7a79cbb55643
RD901F-40-15R1 v041 x 3
RD901F-40-15R1 v044 x 3
RD901F-40-15R1 v043 x 3
RD901F-40-15R1 v042 x 3
RD901F-40-15R1 v036 x 3
RD901F-40-15R1 v038 x 3
RD901F-40-15R1 v040 x 3
RD901F-40-15R1 v037 x 3
RD901F-40-15R1 v039 x 3
RV100_Knob_ea79e50ac817[2] x 3
Plastic_Housing002 x 2
Pin016 x 2
Pin015 x 2
Pin013 x 2
Shield002 x 2
Shaft002 x 2
Pin018 x 2
Pin014 x 2
Pin017 x 2
Pcb_e0ed001
R6_R_0603_1608Metric_e373ab3427fa001 x 6
TP2_TestPoint_Bridge_Pitch2.54mm_Drill1.0mm_f495187aaf005 x 3
C5_C_0603_1608Metric_ed839cd67f007 x 3
U1_SOIC_8_39x49mm_P127mm_a43be1e7514e001
Q1_SOT_23_534e9f9556c009
C3_C_0805_2012Metric_f14ae5192a1e001
3PDT Body001
3PDT Cover001
3PDT Pin017
3PDT Pin012
3PDT Pin013
3PDT Pin011
3PDT Pin010
3PDT Pin015
3PDT Pin016
3PDT Pin014
3PDT Pin009
3PDT Schalter001
D1_LED_D5.0mm_26b9df9aa128
D1_Body004_26b9df9aa127[2]001 x 6
jack001
nut001
C1_CP_Radial_D50mm_P200mm_51f96d1c692f001
LEDSpacer

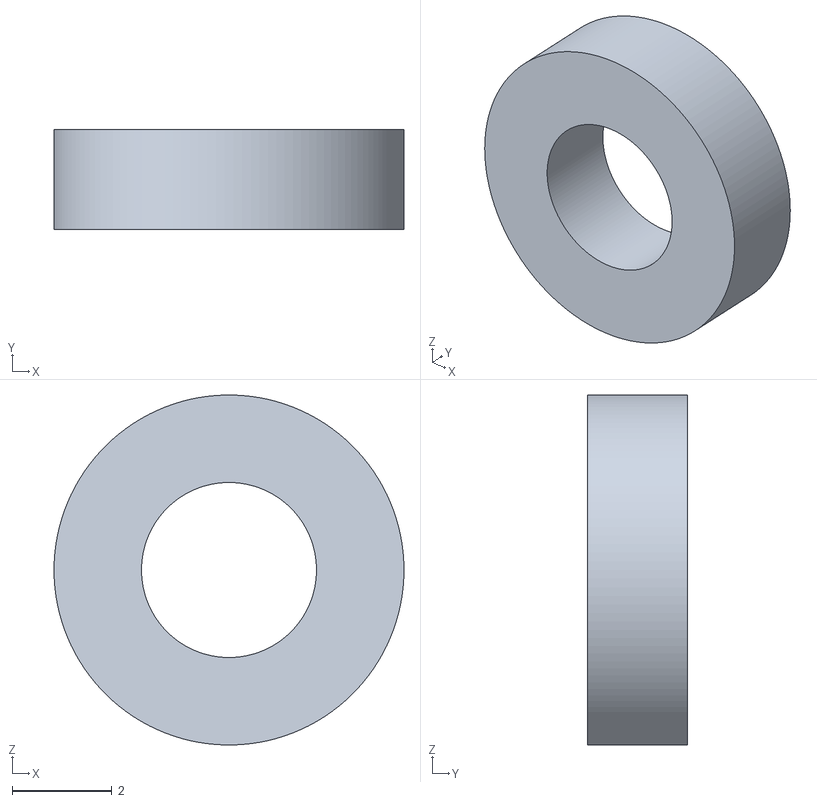
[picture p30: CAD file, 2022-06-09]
3d/BaseRaw/Screw_Filler_Printable_ce0ce63.stl
7.00 x 2.00 x 7.00

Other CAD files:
3d/BaseRaw/1590B_ForManufacturing_ab95e2a.step

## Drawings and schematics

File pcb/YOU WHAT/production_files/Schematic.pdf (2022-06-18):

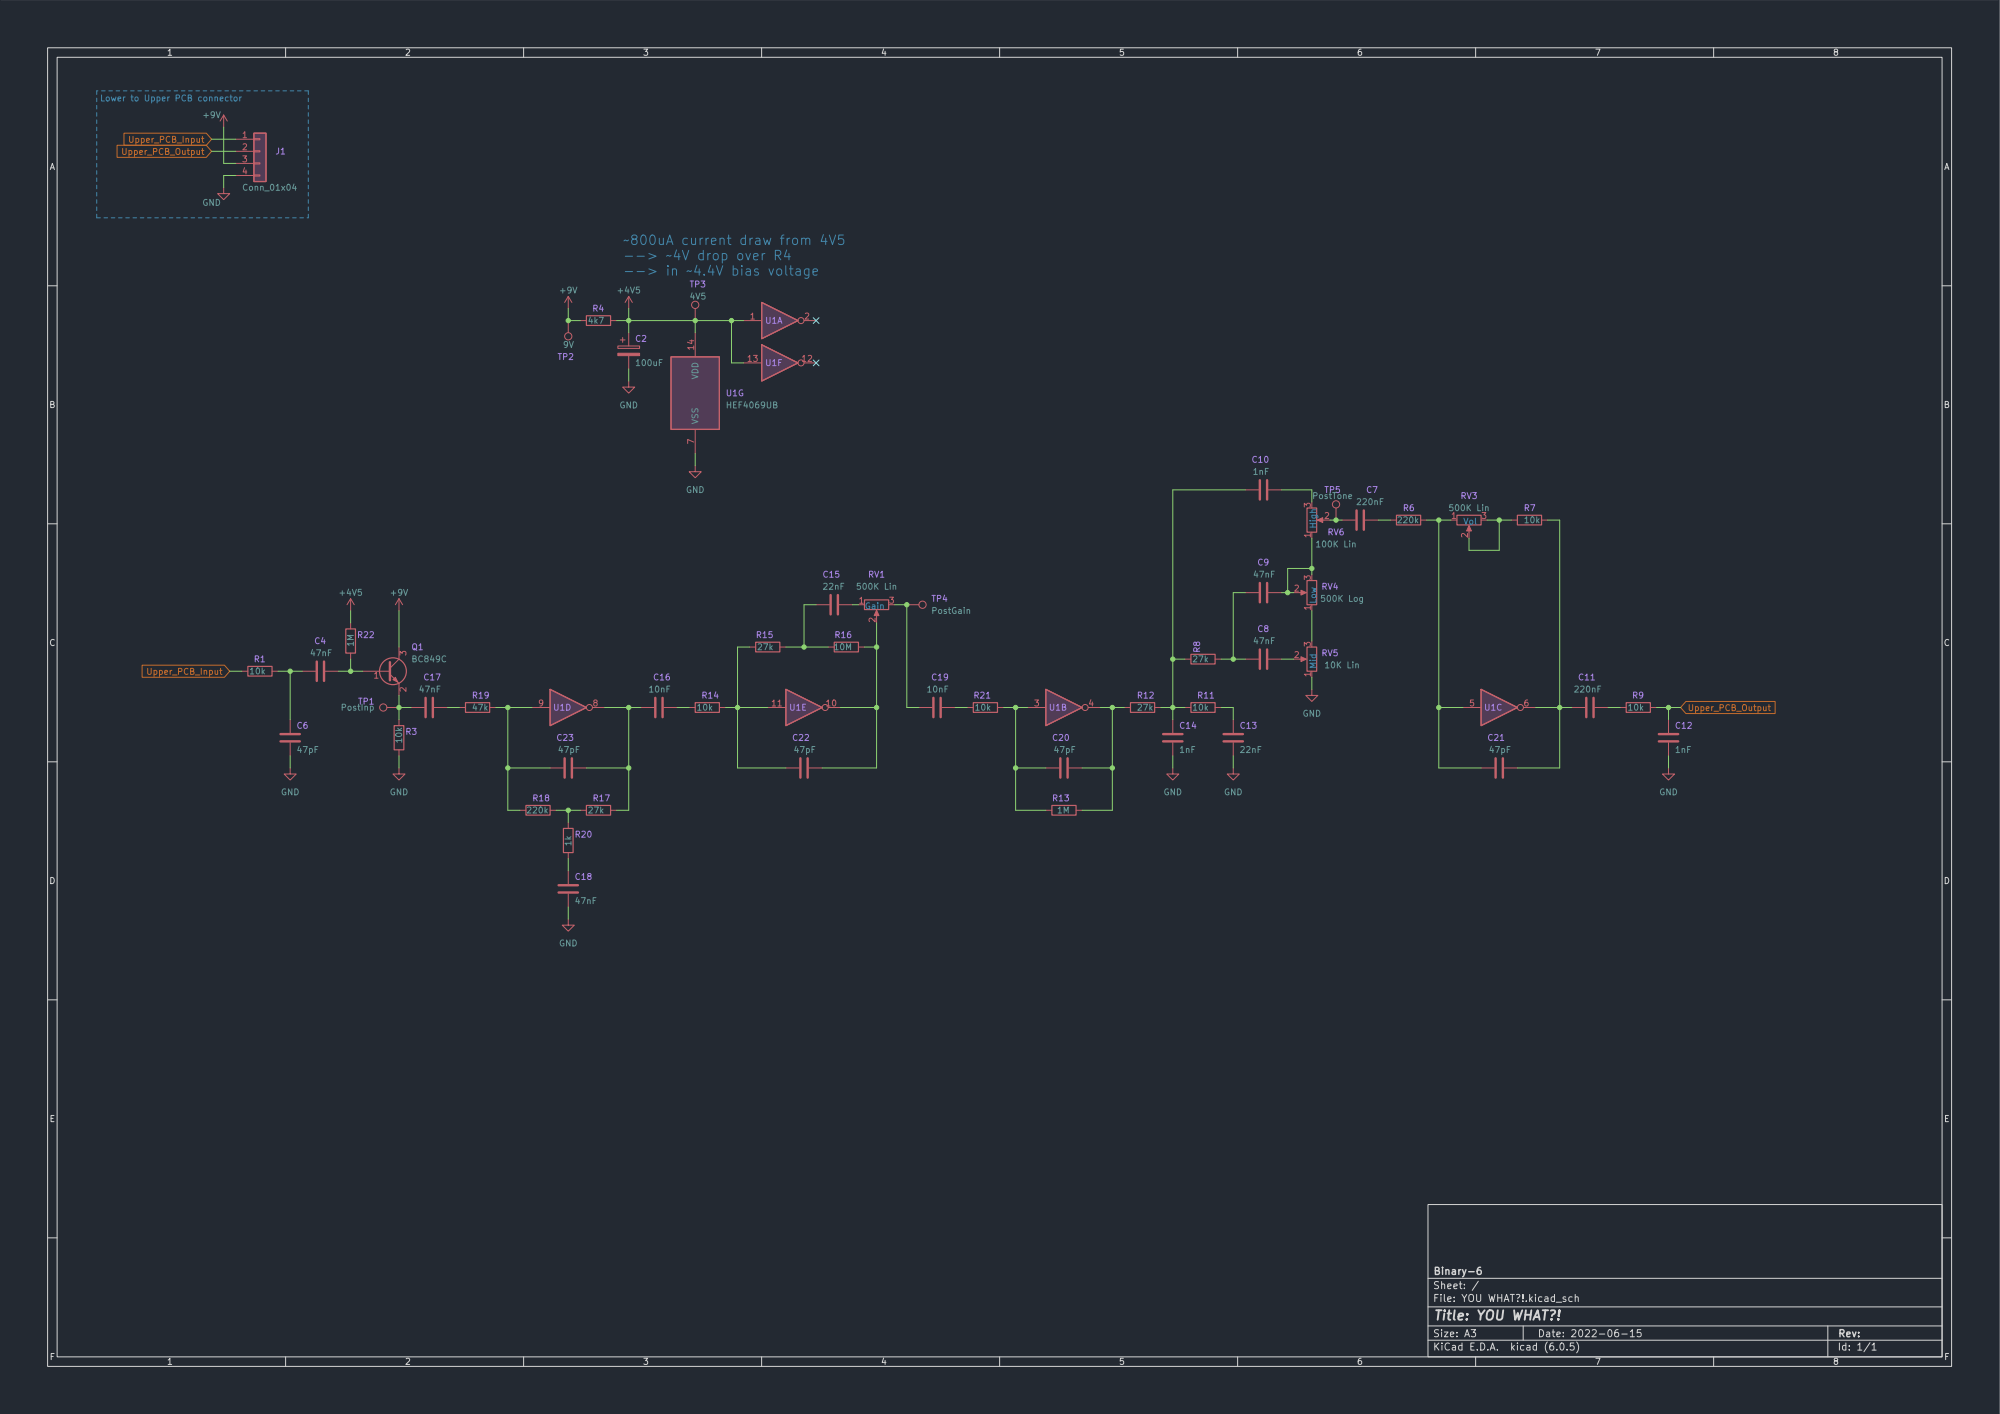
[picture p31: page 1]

File: YOU WHAT?!.kicad_sch Sheet: / Binary-6

Id: 1/1 Title: YOU WHAT?!

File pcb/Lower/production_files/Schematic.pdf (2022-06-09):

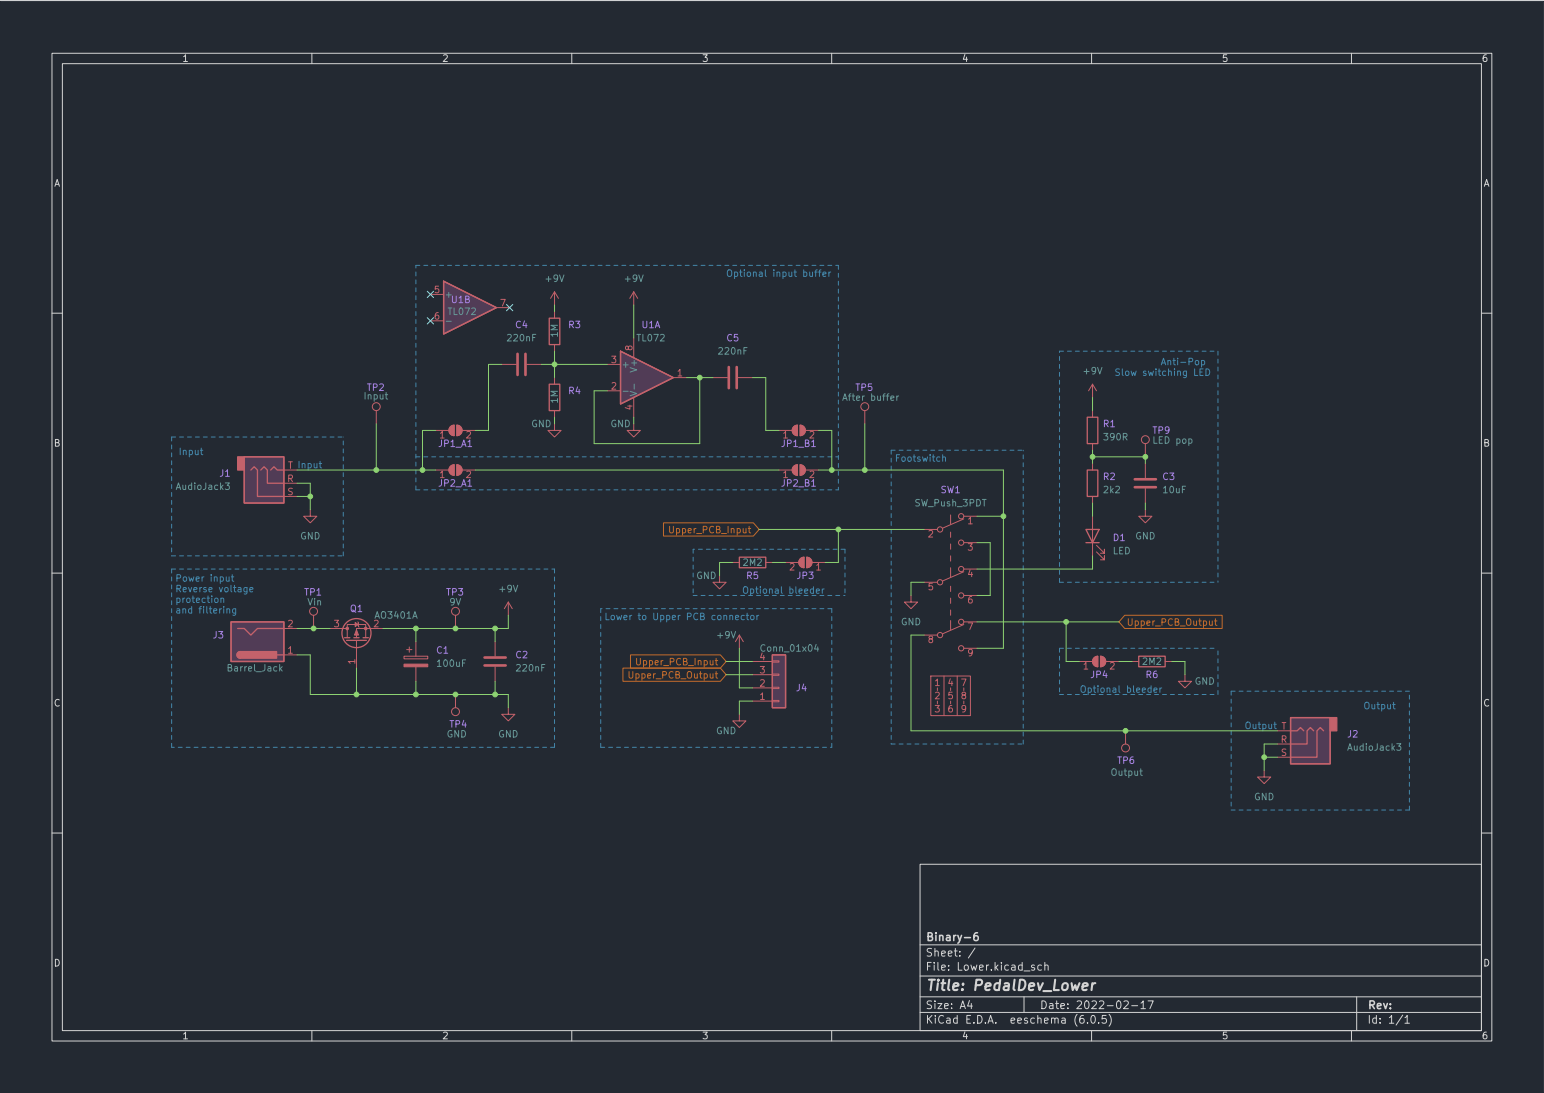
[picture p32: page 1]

Footswitch Optional input buffer

Lower to Upper PCB connector

File: Lower.kicad_sch Sheet: / Binary-6

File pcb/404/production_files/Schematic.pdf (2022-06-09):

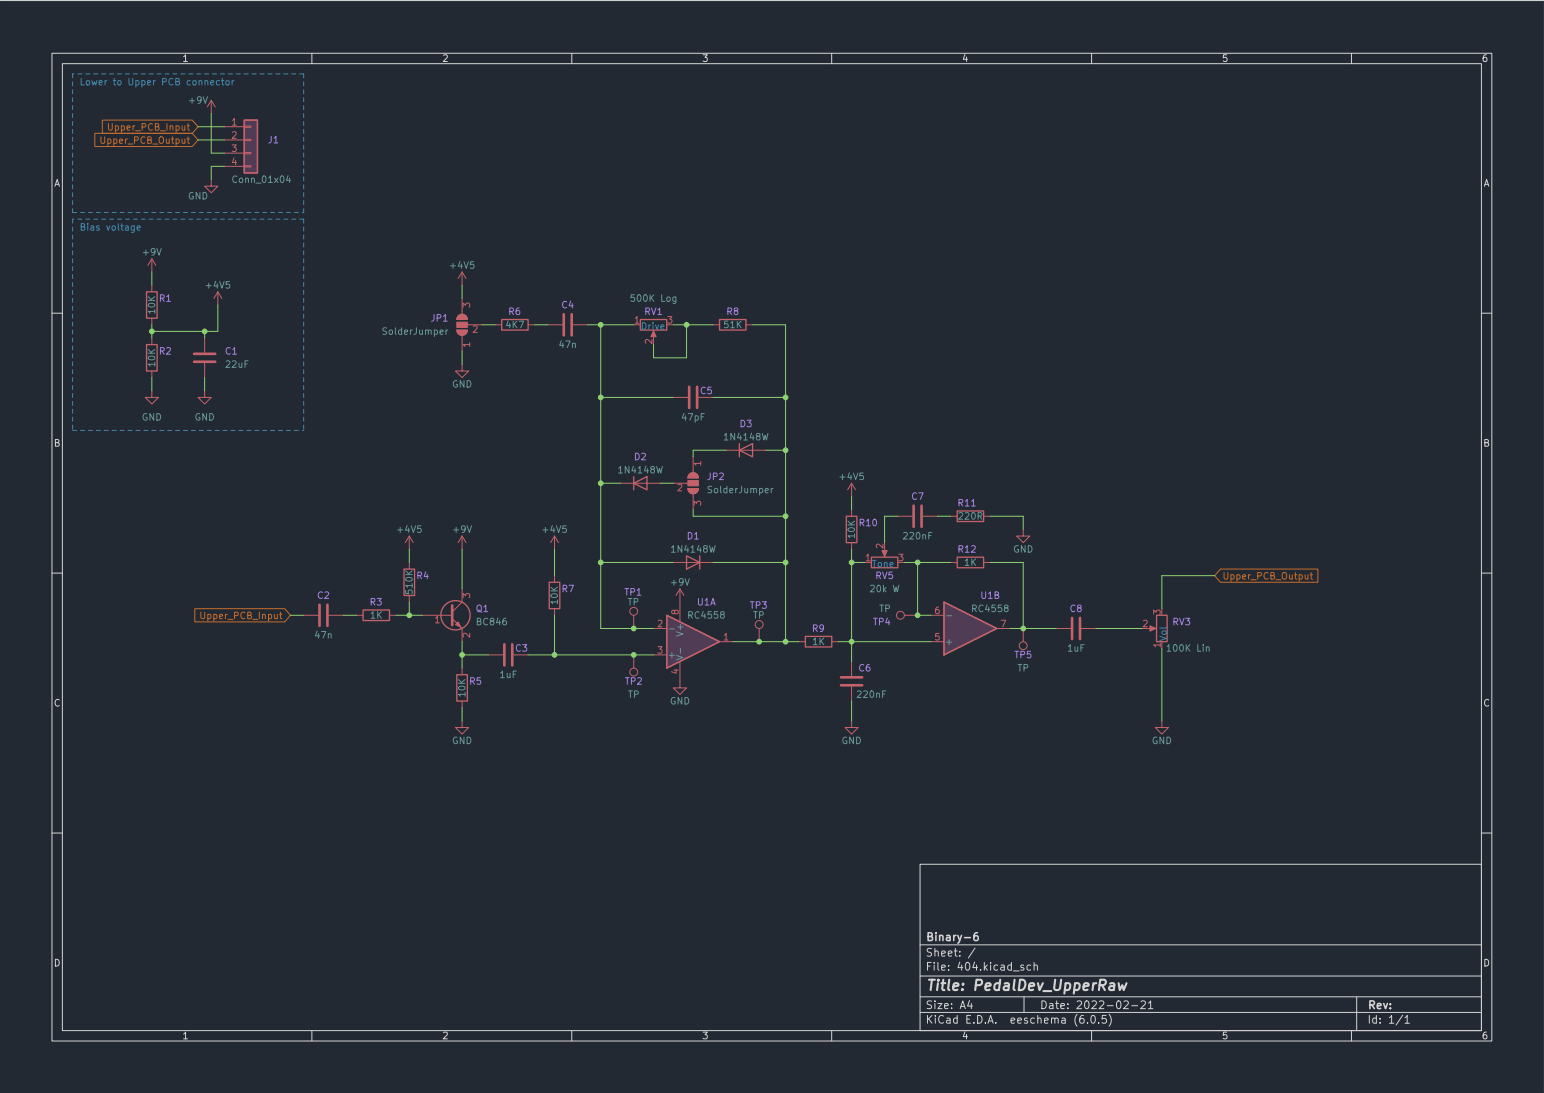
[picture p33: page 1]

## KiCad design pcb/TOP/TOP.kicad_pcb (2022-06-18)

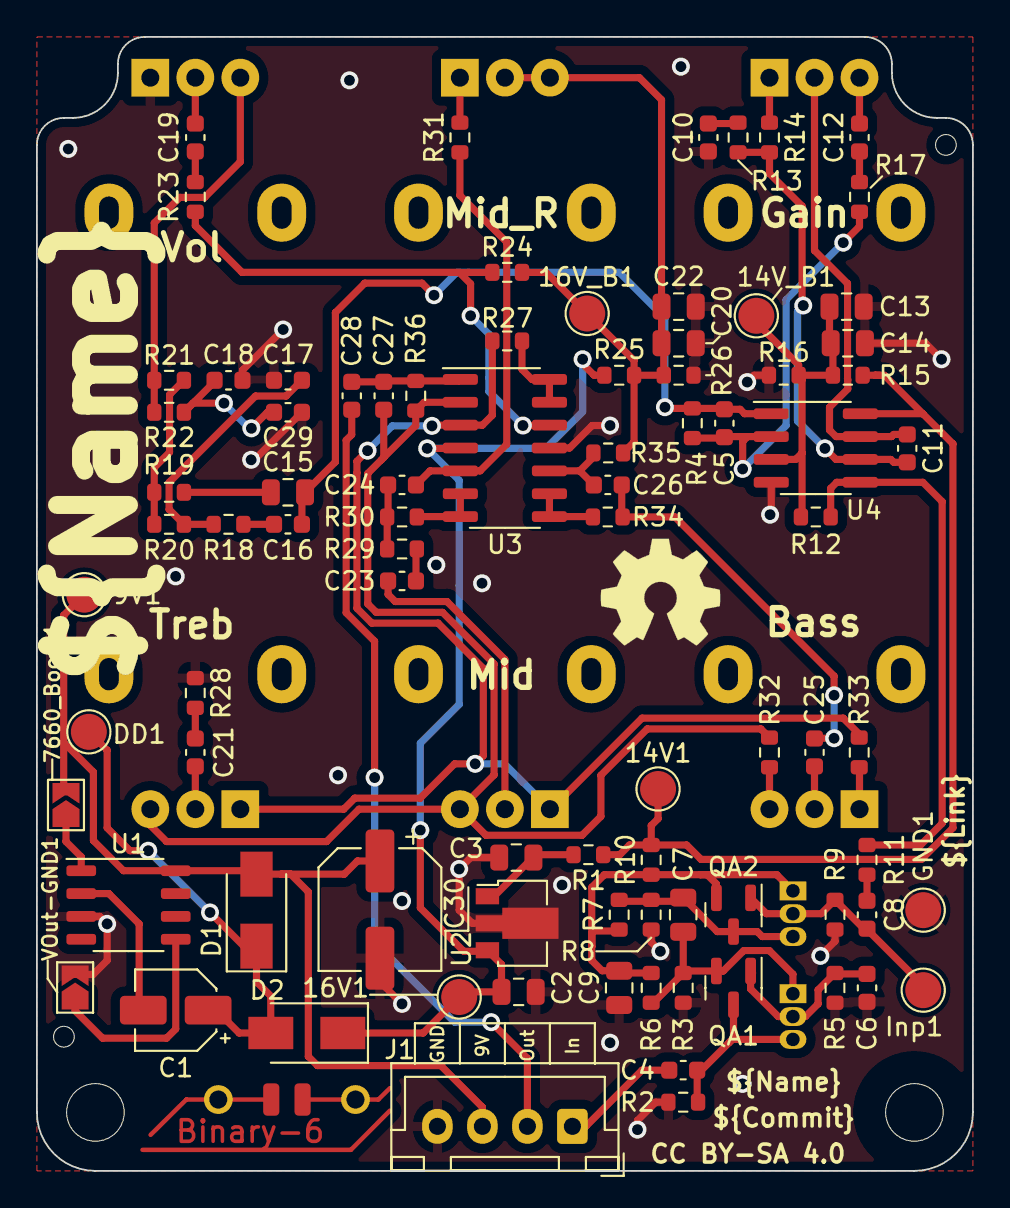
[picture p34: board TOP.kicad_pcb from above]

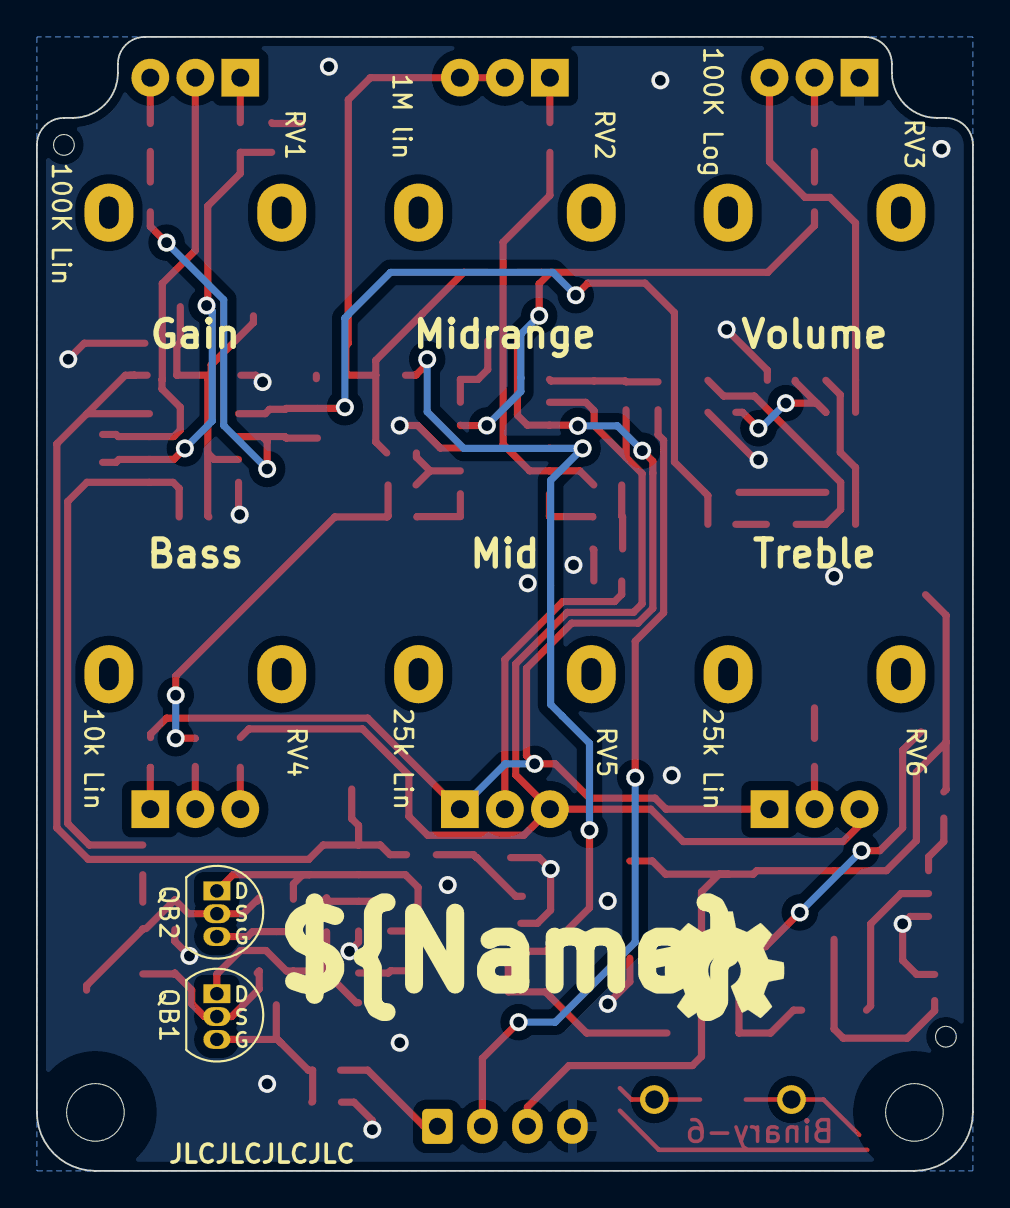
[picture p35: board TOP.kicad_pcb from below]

Board: 2 copper layers, 52.0 x 63.0 mm, 96 parts (8 on the bottom side), 56 nets.

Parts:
9V1, 14V1, 14V_B1, 16V1, 16V_B1: TP; TestPoint_Pad_D2.0mm
7660_Boost1: Jmp; SolderJumper-2_P1.3mm_Open_TrianglePad1.0x1.5mm
C1: 10uF; CP_Elec_4x5.4
C2, C3, C9, C13, C14, C20, C22: 10uF; C_0805_2012Metric
C4, C21, C23, C24: 22nF; C_0603_1608Metric
C5: 470pF; C_0603_1608Metric
C6: 2.2uF; C_0603_1608Metric
C7, C15: 10nF; C_0805_2012Metric
C8, C10, C16, C25: 220nF; C_0603_1608Metric
C11: 100pF; C_0603_1608Metric
C12: 100nF; C_0603_1608Metric
C17: 47nF; C_0603_1608Metric
C18, C27, C29: 1nF; C_0603_1608Metric
C19, C28: 470nF; C_0603_1608Metric
C26: 68nF; C_0603_1608Metric
C30: 100uF; CP_Elec_6.3x5.4_Nichicon
D1, D2: 1N4004; D_SMA
DD1: TP; TestPoint_Pad_D2.0mm
GND1: TP; TestPoint_Pad_D2.0mm
H7: Symbol_Binary6; Binary_6_v0.1_tiny_silk
Inp1: TP; TestPoint_Pad_D2.0mm
J1: Conn_01x04; JST_XH_B4B-XH-A_1x04_P2.50mm_Vertical
MK2, MK2#2: Mounting_Hole_M3; EigenesMountingHole_3.2mm_M3_Small
QA1, QA2: BF545A; SOT-23
QB1, QB2: BF245A; TO-92L_Inline
R1: 51R; R_0603_1608Metric
R2, R4, R24: 1M; R_0603_1608Metric
R3, R5, R6, R9, R15, R16, R18, R25, R26, R27, R31, R33, R36: 10K; R_0603_1608Metric
R7, R8, R35: 470K; R_0603_1608Metric
R10, R28: 2K2; R_0603_1608Metric
R11: 22K; R_0603_1608Metric
R12: 100K; R_0603_1608Metric
R13, R23, R32: 1K; R_0603_1608Metric
R14, R29: 7K5; R_0603_1608Metric
R17: 15K; R_0603_1608Metric
R19, R20, R21: 47K; R_0603_1608Metric
R22: 39K; R_0603_1608Metric
R30: 470R; R_0603_1608Metric
R34: 330R; R_0603_1608Metric
RV1: 100K Lin; Potentiometer_Alpha_RD901F-40-00D_Single_Vertical
RV2: 1M lin; Potentiometer_Alpha_RD901F-40-00D_Single_Vertical
RV3: 100K Log; Potentiometer_Alpha_RD901F-40-00D_Single_Vertical
RV4: 10k Lin; Potentiometer_Alpha_RD901F-40-00D_Single_Vertical
RV5, RV6: 25k Lin; Potentiometer_Alpha_RD901F-40-00D_Single_Vertical
U1: ICL7660; SOP-8_3.9x4.9mm_P1.27mm
U2: L78L15_SOT89; SOT-89-3
U3: TL074; SOIC-14_3.9x8.7mm_P1.27mm
U4: OPA2604; SOIC-8_3.9x4.9mm_P1.27mm
VOut-GND1: Jmp; SolderJumper-2_P1.3mm_Open_TrianglePad1.0x1.5mm

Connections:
+9V: 9V1.1, 7660_Boost1.2 (B), C30.1, D1.2 (A), J1.3, U1.8 (V+)
+14V: 14V1.1, R1.1, R10.2, R15.1, U4.8 (V+)
+16V: 16V1.1, C2.1, D2.1 (K), R25.1, U2.3 (IN), U3.4 (V+)
GND: C2.2, C3.2, C6.2, C9.2, C10.1, C13.2, C14.2, C17.1, C18.2, C20.2, C22.2, C29.2, C30.2, GND1.1, J1.4, R2.2, R3.1, R5.2, R8.2, R9.2, R16.2, R26.2, R28.1, RV3.1, U1.3 (GND), U2.2 (GND), U3.11 (V-), U4.4 (V-), VOut-GND1.2 (B)
unnamed: 14V_B1.1, C13.1, C14.1, R12.1, R15.2, R16.1, U4.3 (+)
unnamed: 16V_B1.1, C20.1, C22.1, R24.1, R25.2, R26.1, R35.2, RV2.2, RV2.3
unnamed: C1.1, D1.1 (K), D2.2 (A), DD1.1
unnamed: C1.2, U1.2 (CAP+)
unnamed: C3.1, R1.2, U2.1 (OUT)
unnamed: C4.1, QA1.3 (G), QB1.3 (G), R2.1
unnamed: C5.2, R4.1, R17.2, U4.2 (-)
unnamed: C6.1, QA1.1 (S), QB1.2 (S), R5.1
unnamed: C7.1, QA2.3 (G), QB2.3 (G), R7.2, R8.1
unnamed: C7.2, QA1.2 (D), QB1.1 (D), R3.2, R6.1
unnamed: C8.1, R11.1
unnamed: C8.2, Inp1.1, QA2.1 (S), QB2.2 (S), R9.1
unnamed: C9.1, QA2.2 (D), QB2.1 (D), R6.2, R7.1, R10.1
unnamed: C10.2, R13.1
unnamed: C11.1, RV1.2, U4.7
unnamed: C11.2, R13.2, R14.1, U4.6 (-)
unnamed: C12.1, R17.1
unnamed: C12.2, RV1.3
unnamed: C15.1, R19.1
unnamed: C5.1, C15.2, C16.1, R4.2, U4.1
unnamed: C16.2, R18.1
unnamed: C17.2, R18.2, R20.1
unnamed: C18.1, C29.1, R22.2
unnamed: C19.1, R23.1
unnamed: C19.2, RV3.2
unnamed: C21.1, RV6.2
unnamed: C21.2, R28.2
unnamed: C23.1, R29.2
unnamed: C23.2, RV5.2
unnamed: C24.1, R31.2, U3.5 (+)
unnamed: C24.2, R29.1, R30.1
unnamed: C25.1, C26.2, R34.1
unnamed: C25.2, RV4.2
unnamed: C26.1, R35.1, U3.10 (+)
unnamed: C27.1, C28.2, R36.2, U3.1
unnamed: C27.2, R32.1, R36.1, RV5.3, RV6.3, U3.2 (-)
unnamed: R11.2, R12.2, U4.5 (+)
unnamed: R14.2, RV1.1
unnamed: R19.2, R20.2, R21.1
unnamed: R21.2, R22.1, RV3.3
unnamed: R23.2, R24.2, U3.12 (+)
unnamed: R27.1, U3.13 (-), U3.14
unnamed: R27.2, R33.2, RV5.1, RV6.1, U3.3 (+)
unnamed: R30.2, U3.6 (-), U3.7
unnamed: R31.1, RV2.1
unnamed: R32.2, RV4.3
unnamed: R33.1, RV4.1
unnamed: R34.2, U3.8, U3.9 (-)
unnamed: 7660_Boost1.1 (A), U1.1 (BOOST)
unnamed: U1.5 (VOUT), VOut-GND1.1 (A)
Upper_PCB_Input: C4.2, J1.1
Upper_PCB_Output: C28.1, J1.2

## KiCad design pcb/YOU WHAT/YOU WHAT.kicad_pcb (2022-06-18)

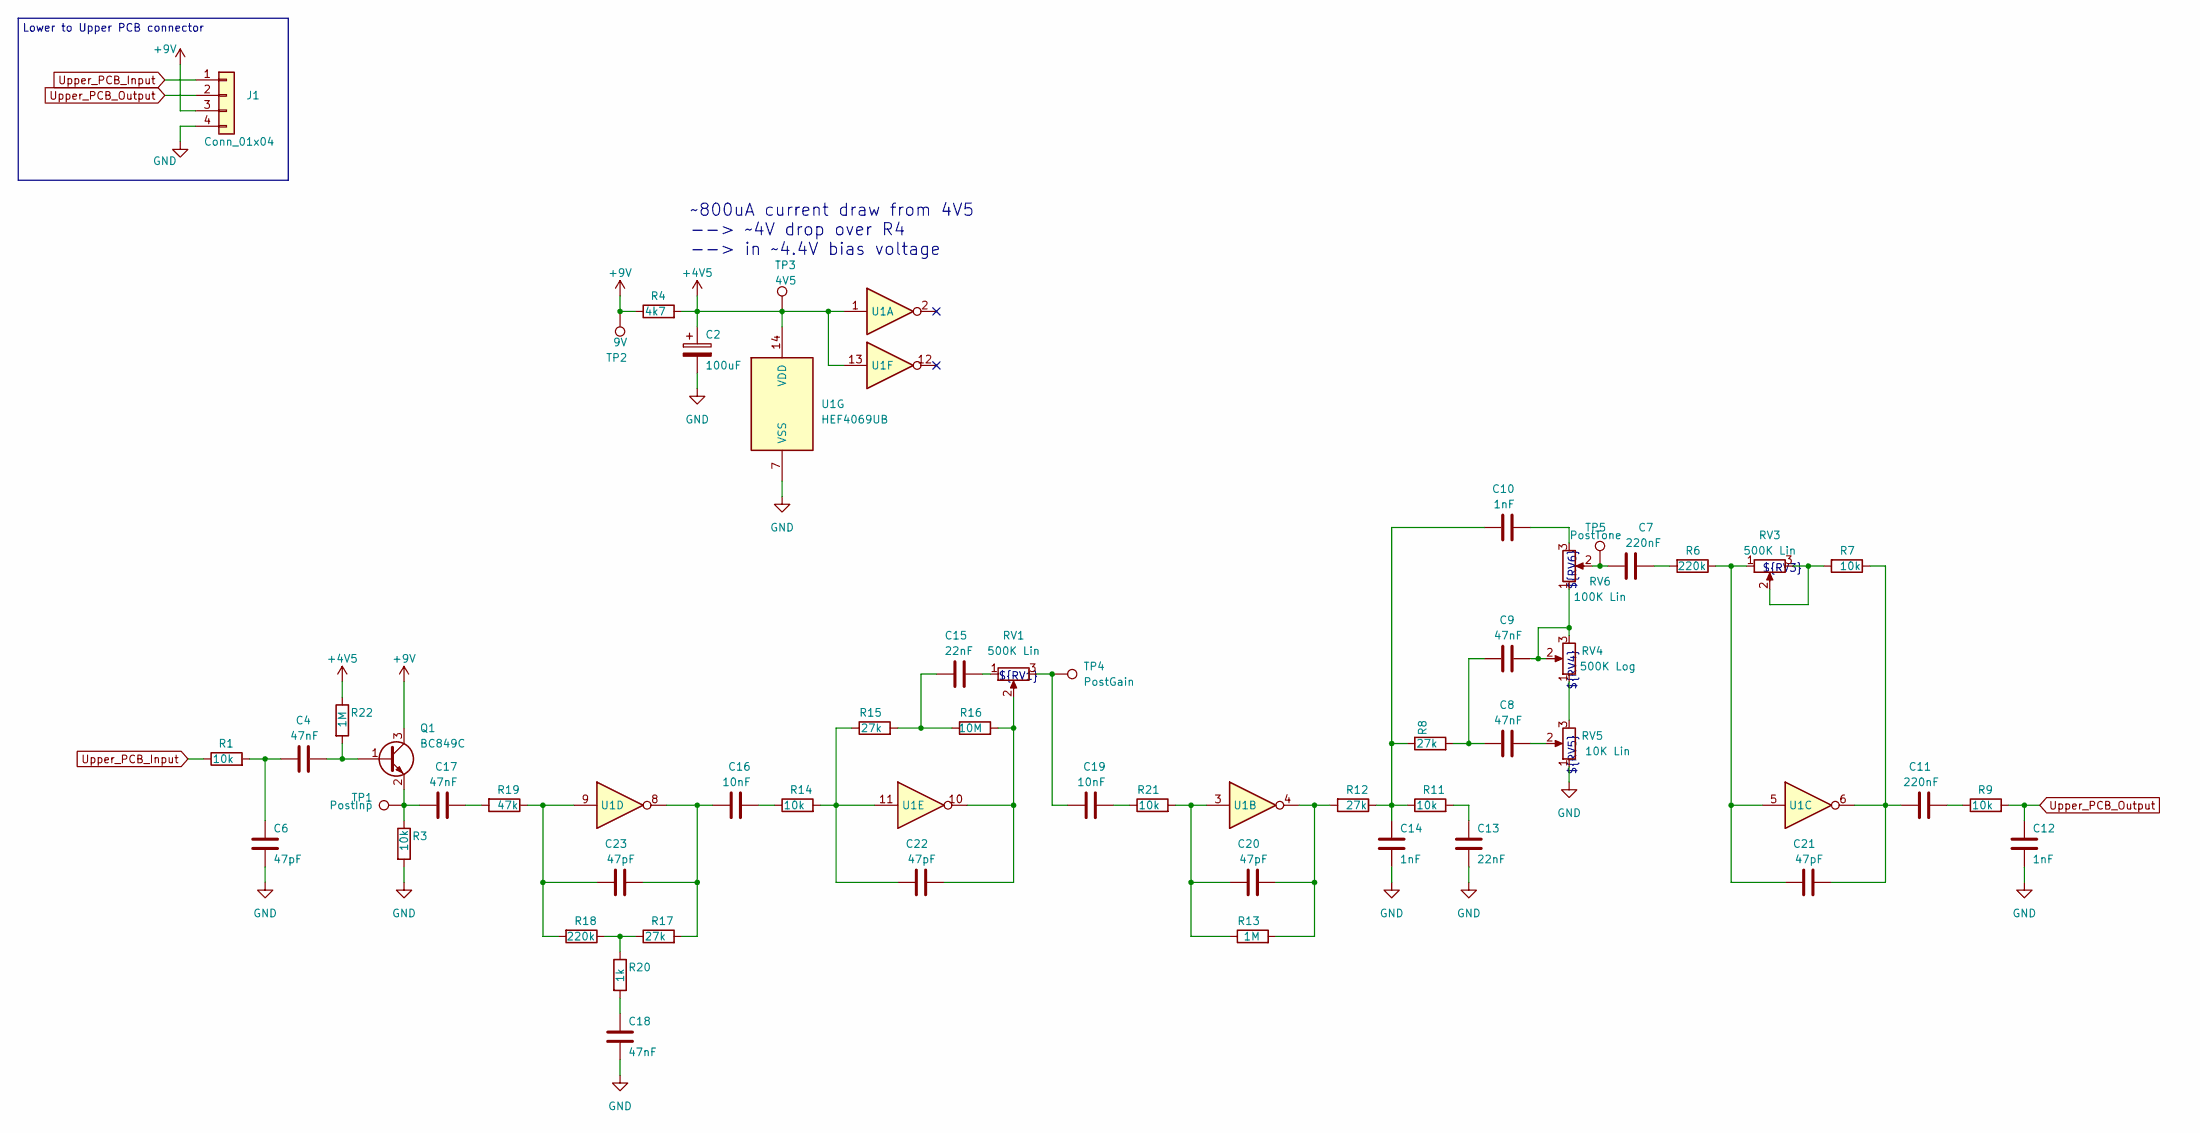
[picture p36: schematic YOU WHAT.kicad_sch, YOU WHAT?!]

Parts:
C2: 100uF; CP_Elec_6.3x5.3; LCSC C134723
C4, C8, C9, C17, C18: 47nF; C_0603_1608Metric; LCSC C1622
C6, C20, C21, C22, C23: 47pF; C_0603_1608Metric; LCSC C1671
C7, C11: 220nF; C_0603_1608Metric; LCSC C21120
C10, C12, C14: 1nF; C_0603_1608Metric; LCSC C1588
C13, C15: 22nF; C_0603_1608Metric; LCSC C21122
C16, C19: 10nF; C_0603_1608Metric; LCSC C57112
J1: Conn_01x04; JST_XH_B4B-XH-A_1x04_P2.50mm_Vertical; LCSC C144395
Q1: BC849C; SOT-23; LCSC C334244
R1, R3, R7, R9, R11, R14, R21: 10k; R_0603_1608Metric; LCSC C25804
R4: 4k7; R_0603_1608Metric; LCSC C23162
R6, R18: 220k; R_0603_1608Metric; LCSC C22961
R8, R12, R15, R17: 27k; R_0603_1608Metric; LCSC C22967
R13, R22: 1M; R_0603_1608Metric; LCSC C22935
R16: 10M; R_0603_1608Metric; LCSC C7250
R19: 47k; R_0603_1608Metric; LCSC C25819
R20: 1k; R_0603_1608Metric; LCSC C21190
RV1, RV3: 500K Lin; Potentiometer_Alpha_RD901F-40-00D_Single_Vertical
RV4: 500K Log; Potentiometer_Alpha_RD901F-40-00D_Single_Vertical
RV5: 10K Lin; Potentiometer_Alpha_RD901F-40-00D_Single_Vertical
RV6: 100K Lin; Potentiometer_Alpha_RD901F-40-00D_Single_Vertical
TP1: PostInp; TestPoint_Pad_D2.0mm
TP2: 9V; TestPoint_Pad_D2.0mm
TP3: 4V5; TestPoint_Pad_D2.0mm
TP4: PostGain; TestPoint_Pad_D2.0mm
TP5: PostTone; TestPoint_Pad_D2.0mm
U1: HEF4069UB; SOIC-14_3.9x8.7mm_P1.27mm; LCSC C6739

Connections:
+4V5: C2.1, R4.2, R22.1, TP3.1, U1.1, U1.13, U1.14 (VDD)
+9V: J1.3, Q1.3 (C), R4.1, TP2.1
GND: C2.2, C6.2, C12.2, C13.2, C14.2, C18.2, J1.4, R3.2, RV5.1, U1.7 (VSS)
unnamed: C4.1, C6.1, R1.2
unnamed: C4.2, Q1.1 (B), R22.2
unnamed: C7.1, RV6.2, TP5.1
unnamed: C7.2, R6.2
unnamed: C8.1, C9.1, R8.2
unnamed: C8.2, RV5.2
unnamed: C9.2, RV4.2, RV4.3, RV6.1
unnamed: C10.1, C14.1, R8.1, R11.1, R12.1
unnamed: C10.2, RV6.3
unnamed: C11.1, C21.2, R7.1, U1.6
unnamed: C11.2, R9.1
unnamed: C13.1, R11.2
unnamed: C15.1, RV1.1
unnamed: C15.2, R15.2, R16.1
unnamed: C16.1, C23.2, R17.2, U1.8
unnamed: C16.2, R14.1
unnamed: C17.1, Q1.2 (E), R3.1, TP1.1
unnamed: C17.2, R19.2
unnamed: C18.1, R20.2
unnamed: C19.1, RV1.3, TP4.1
unnamed: C19.2, R21.1
unnamed: C20.1, R13.1, R21.2, U1.3
unnamed: C20.2, R12.2, R13.2, U1.4
unnamed: C21.1, R6.1, RV3.1, U1.5
unnamed: C22.1, R14.2, R15.1, U1.11
unnamed: C22.2, R16.2, RV1.2, U1.10
unnamed: C23.1, R18.2, R19.1, U1.9
unnamed: R7.2, RV3.2, RV3.3
unnamed: R17.1, R18.1, R20.1
unnamed: RV4.1, RV5.3
Upper_PCB_Input: J1.1, R1.1
Upper_PCB_Output: C12.1, J1.2, R9.2

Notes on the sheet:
${RV5}
${RV3}
${RV6}
${RV1}
Lower to Upper PCB connector
${RV4}
~800uA current draw from 4V5 --> ~4V drop over R4 --> in ~4.4V bias voltage

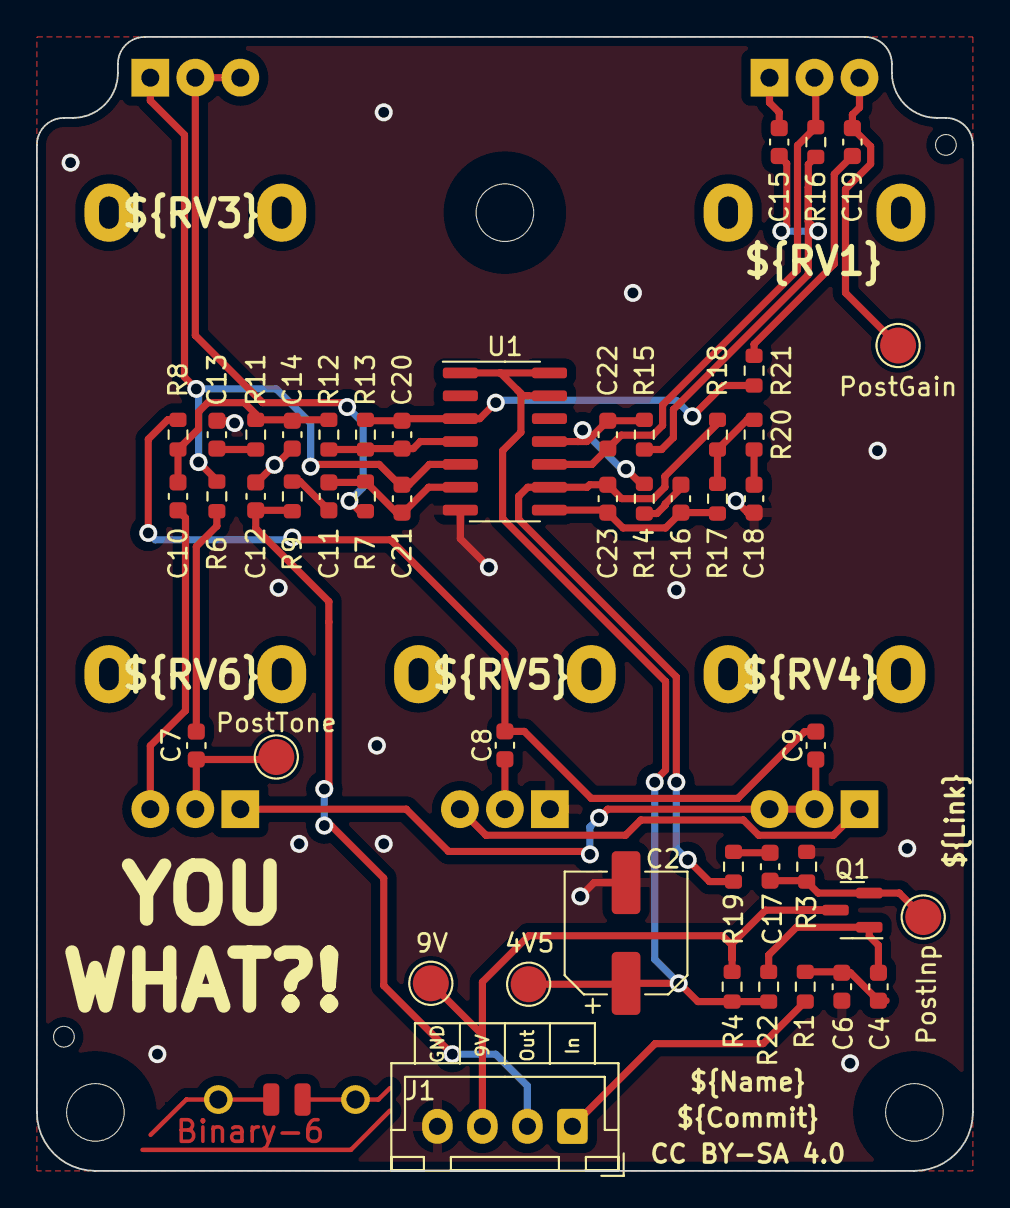
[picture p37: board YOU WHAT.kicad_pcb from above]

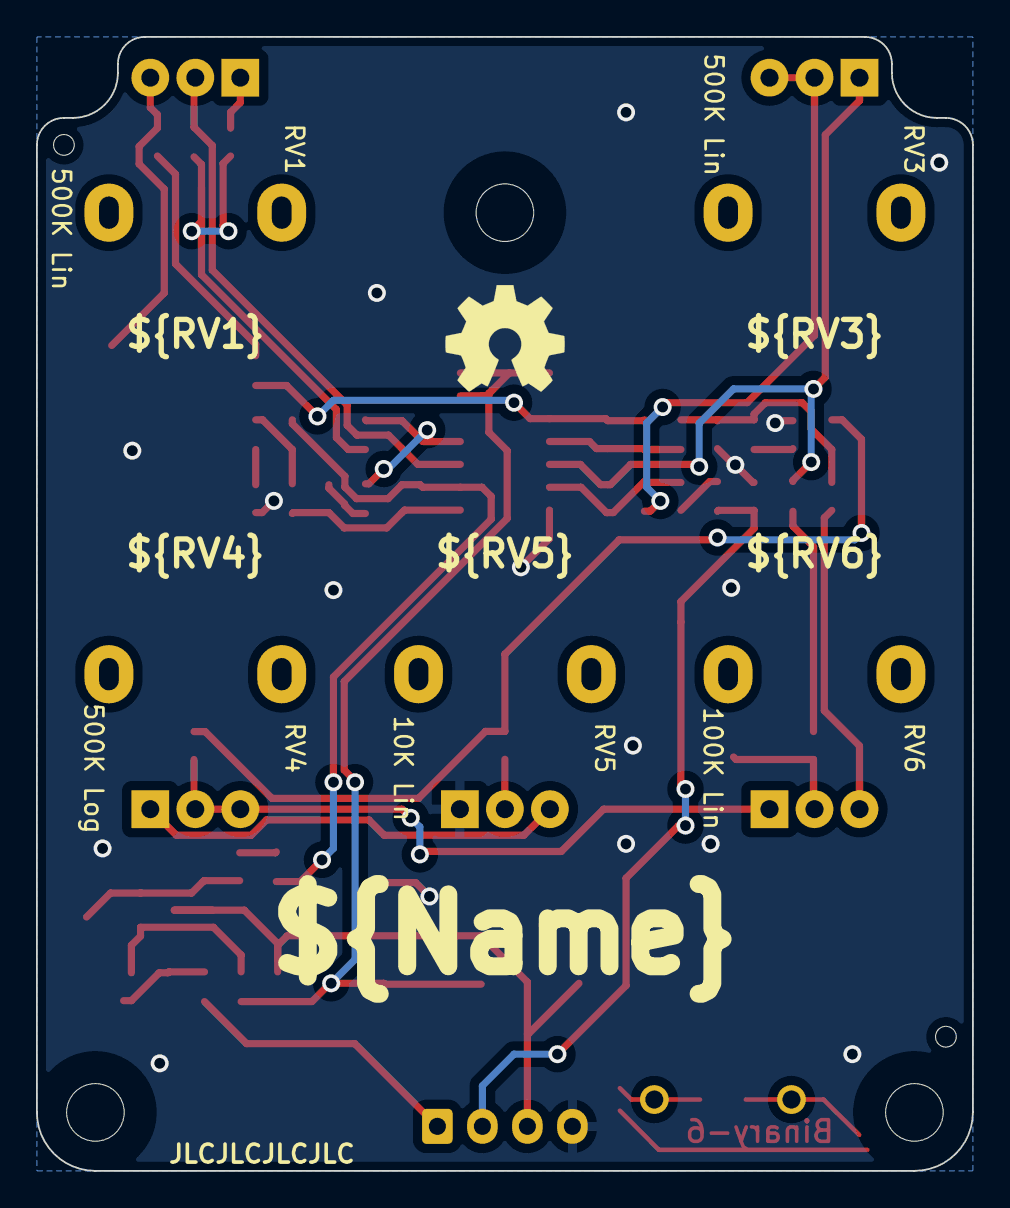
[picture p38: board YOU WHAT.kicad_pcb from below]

Board: 2 copper layers, 52.0 x 63.0 mm, 56 parts (5 on the bottom side), 35 nets.

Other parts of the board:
H7: Symbol_Binary6; Binary_6_v0.1_tiny_silk
MK2, MK2#2, MK2#3: Mounting_Hole_M3; EigenesMountingHole_3.2mm_M3_Small

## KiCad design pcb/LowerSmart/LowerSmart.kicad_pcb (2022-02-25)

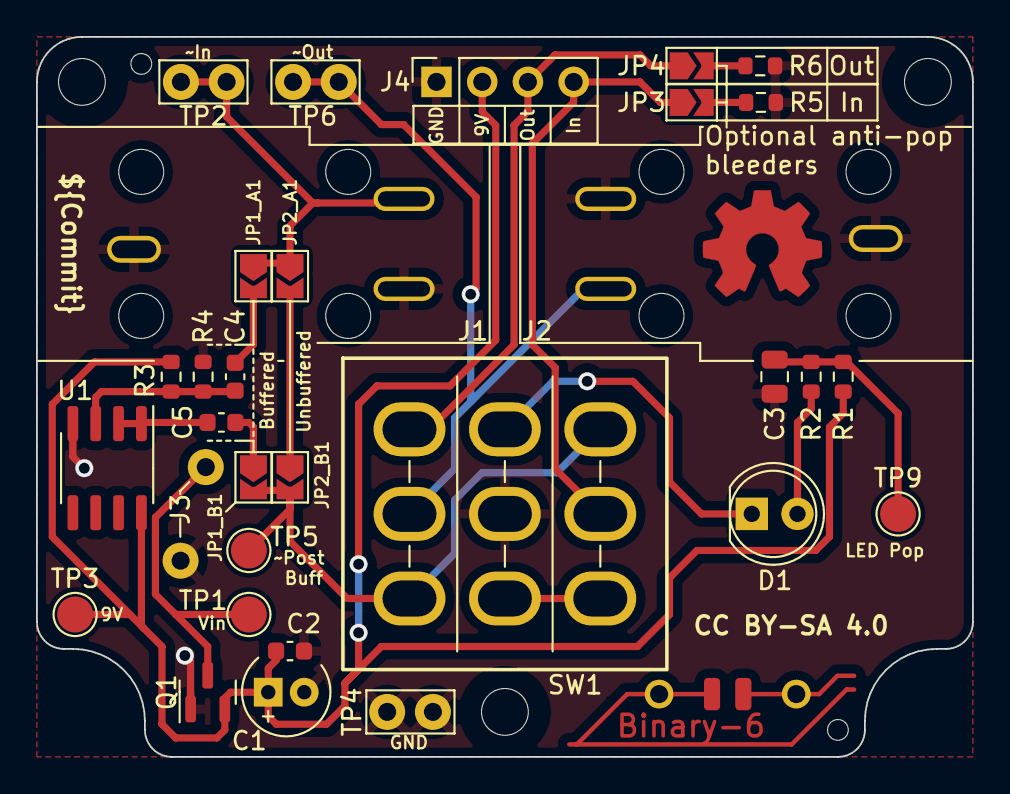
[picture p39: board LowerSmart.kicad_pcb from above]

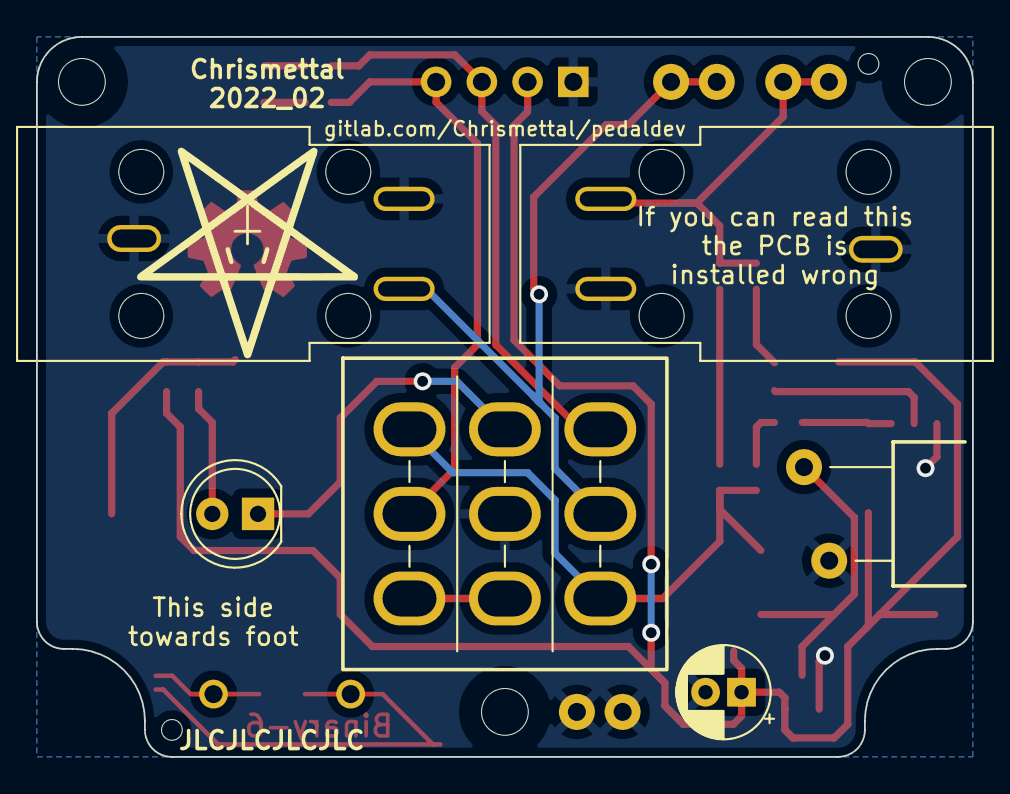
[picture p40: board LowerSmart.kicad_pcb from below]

Board: 2 copper layers, 52.0 x 40.0 mm, 37 parts (7 on the bottom side), 19 nets.

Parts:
C1: 100uF; CP_Radial_D5.0mm_P2.00mm
C2, C4, C5: 220nF; C_0603_1608Metric
C3: 10uF; C_0805_2012Metric
D1: LED; LED_D5.0mm
H7: Symbol_Binary6; Binary_6_v0.1_tiny_silk
J1, J2: AudioJack3; Audio_Jack_PJ-602B
J3: Barrel_Jack; DC_Barrel_Jack_Thinline_Wired_Standing
J4: Conn_01x04; PinSocket_1x04_P2.54mm_Vertical
JP1_A1, JP1_B1, JP2_A1, JP2_B1, JP3, JP4: Jmp; SolderJumper-2_P1.3mm_Open_TrianglePad1.0x1.5mm
MK2, MK2#2, MK2#3: Mounting_Hole; EigenesMountingHole_2.6mm_M2.5_Small
MK6: PentThin
Q1: AO3401A; SOT-23
R1: 390R; R_0603_1608Metric
R2: 2k2; R_0603_1608Metric
R3, R4: 1M; R_0603_1608Metric
R5, R6: 2M2; R_0603_1608Metric
SW1: SW_Push_3PDT; Footswitch_3PDT
TP1: Vin; TestPoint_Pad_D2.0mm
TP2: Input; TestPoint_Bridge_Pitch2.54mm_Drill1.0mm
TP3: 9V; TestPoint_Pad_D2.0mm
TP4: GND; TestPoint_Bridge_Pitch2.54mm_Drill1.0mm
TP5: After buffer; TestPoint_Pad_D2.0mm
TP6: Output; TestPoint_Bridge_Pitch2.54mm_Drill1.0mm
TP9: LED pop; TestPoint_Pad_D2.0mm
U1: TL072; SOIC-8_3.9x4.9mm_P1.27mm

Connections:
+9V: C1.1, C2.1, J4.2, Q1.2 (S), R1.1, R3.1, TP3.1, U1.8 (V+)
/Input: J1.T, JP1_A1.1 (A), JP2_A1.1 (A), TP2.1
/Output: J2.T, SW1.8 (B), TP6.1
GND: C1.2, C2.2, C3.2, J1.R, J1.S, J2.R, J2.S, J3.1, J4.1, Q1.1 (G), R4.2, R5.1, R6.1, SW1.5 (B), TP4.1, U1.4 (V-)
unnamed: C3.1, R1.2, R2.1, TP9.1
unnamed: C4.1, JP1_A1.2 (B)
unnamed: C4.2, R3.2, R4.1, U1.3 (+)
unnamed: C5.1, U1.1, U1.2 (-)
unnamed: C5.2, JP1_B1.1 (A)
unnamed: D1.1 (K), SW1.4 (A)
unnamed: D1.2 (A), R2.2
unnamed: J3.2, Q1.3 (D), TP1.1
unnamed: JP1_B1.2 (B), JP2_B1.2 (B), SW1.1 (A), SW1.9 (C), TP5.1
unnamed: JP2_A1.2 (B), JP2_B1.1 (A)
unnamed: JP3.2 (B), R5.2
unnamed: JP4.2 (B), R6.2
unnamed: SW1.3 (C), SW1.6 (C)
Upper_PCB_Input: J4.4, JP3.1 (A), SW1.2 (B)
Upper_PCB_Output: J4.3, JP4.1 (A), SW1.7 (A)

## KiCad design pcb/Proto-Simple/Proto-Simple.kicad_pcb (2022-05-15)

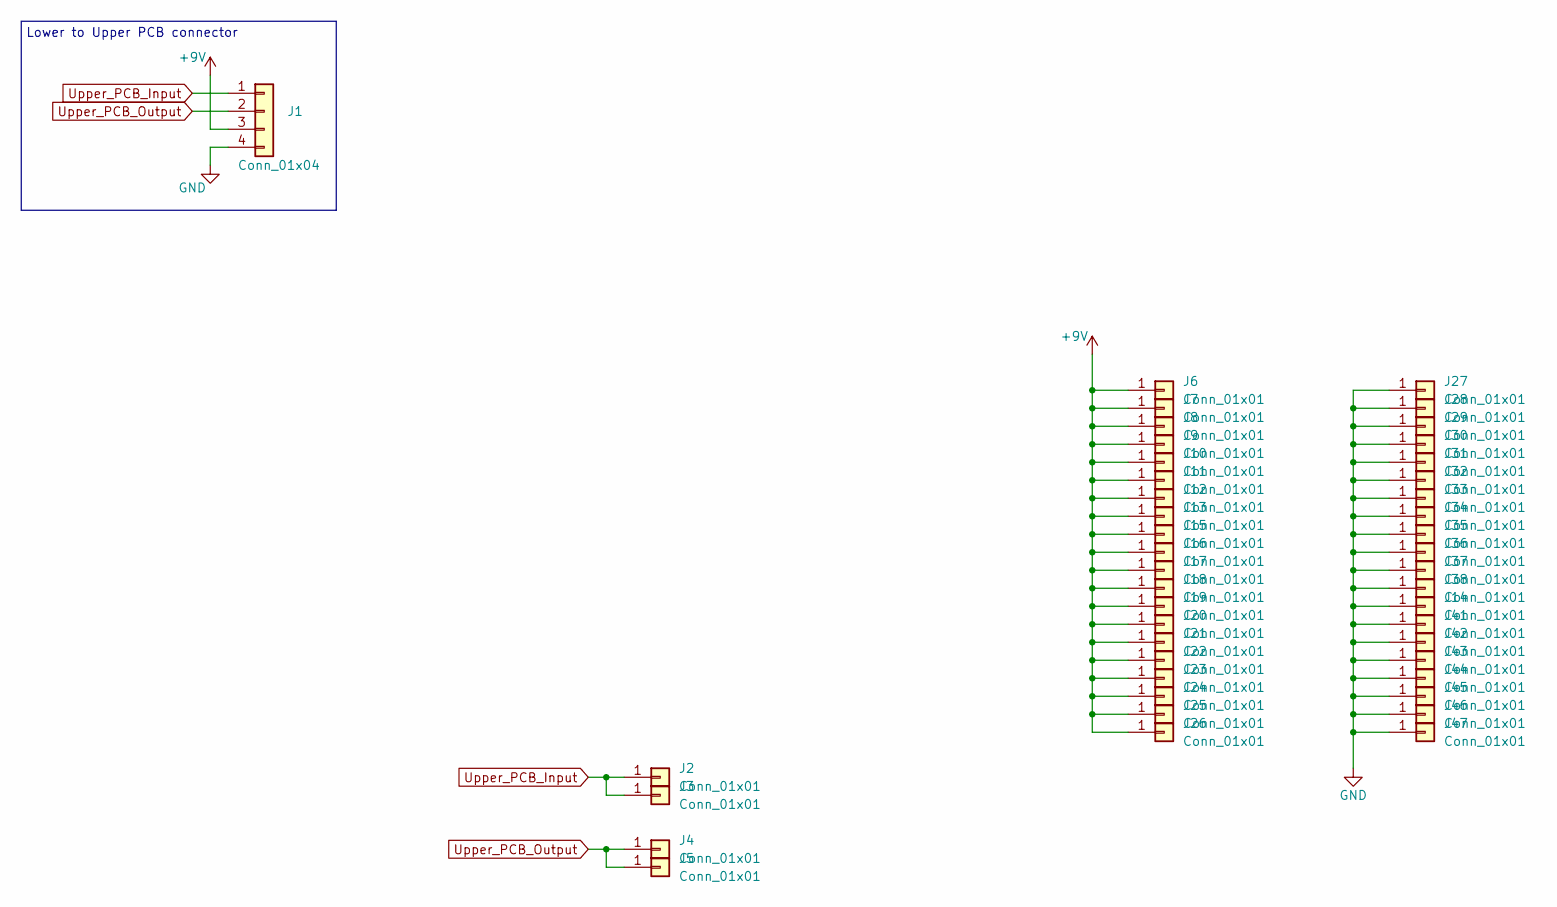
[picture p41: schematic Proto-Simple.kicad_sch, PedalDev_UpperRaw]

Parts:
J1: Conn_01x04; JST_XH_B4B-XH-A_1x04_P2.50mm_Vertical; LCSC^ C144395
J2, J3, J4, J5, J6, J7, J8, J9, J10, J11, J12, J13, J14, J15, J16, J17, J18, J19, J20, J21, J22, J23, J24, J25, J26, J27, J28, J29, J30, J31, J32, J33, J34, J35, J36, J37, J38, J41, J42, J43, J44, J45, J46, J47: Conn_01x01; Protopin_Small

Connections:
+9V: J1.3, J6.1, J7.1, J8.1, J9.1, J10.1, J11.1, J12.1, J13.1, J15.1, J16.1, J17.1, J18.1, J19.1, J20.1, J21.1, J22.1, J23.1, J24.1, J25.1, J26.1
GND: J1.4, J14.1, J27.1, J28.1, J29.1, J30.1, J31.1, J32.1, J33.1, J34.1, J35.1, J36.1, J37.1, J38.1, J41.1, J42.1, J43.1, J44.1, J45.1, J46.1, J47.1
Upper_PCB_Input: J1.1, J2.1, J3.1
Upper_PCB_Output: J1.2, J4.1, J5.1

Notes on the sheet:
Lower to Upper PCB connector

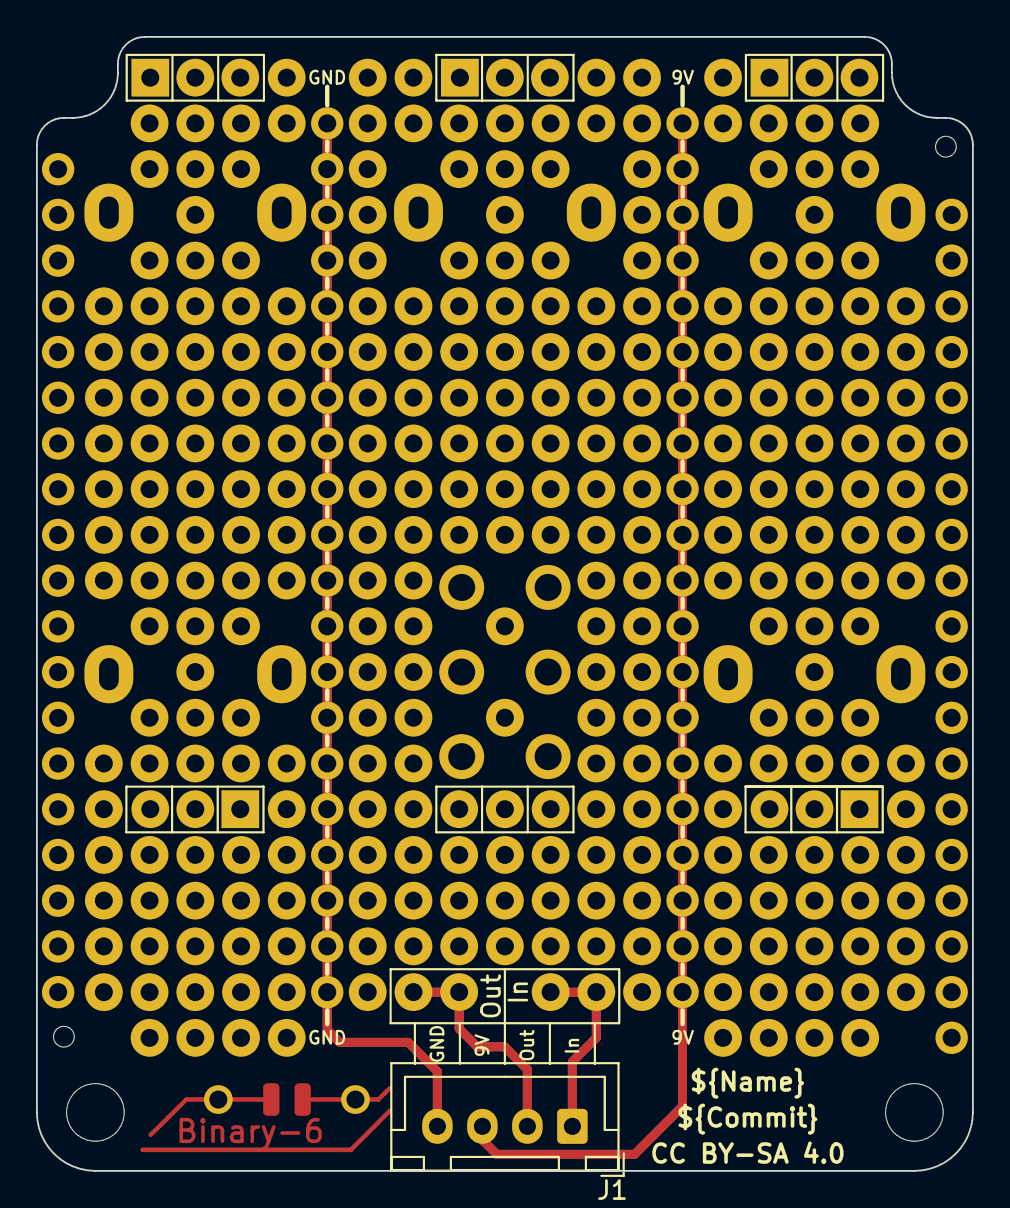
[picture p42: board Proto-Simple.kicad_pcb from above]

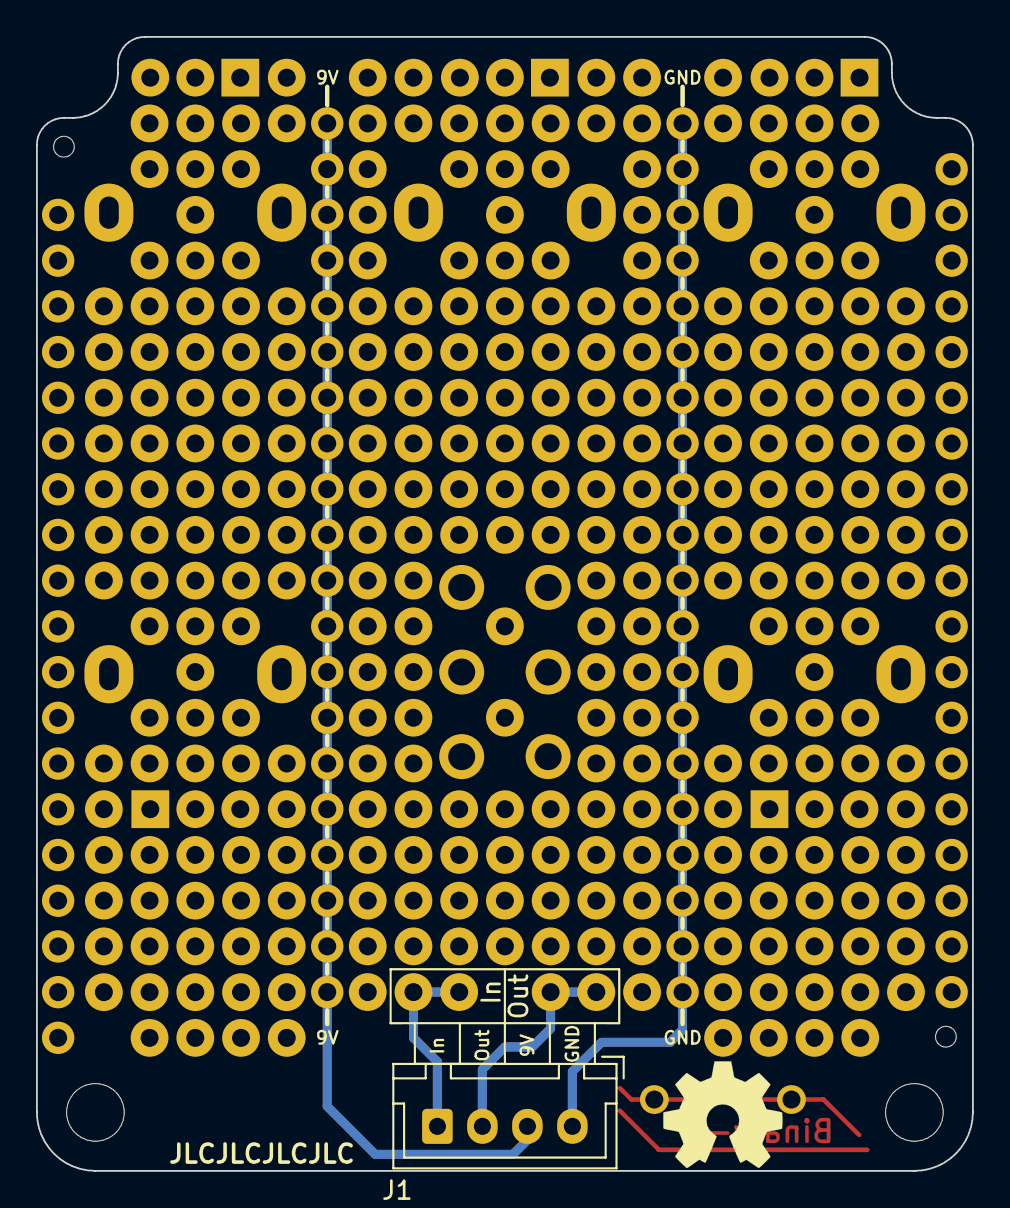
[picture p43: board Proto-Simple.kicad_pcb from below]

Board: 2 copper layers, 52.0 x 63.0 mm, 53 parts (5 on the bottom side), 4 nets.

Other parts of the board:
H7: Symbol_Binary6; Binary_6_v0.1_tiny_silk
MK2, MK2#2: Mounting_Hole_M3; EigenesMountingHole_3.2mm_M3_Small
RV100, RV101, RV102, RV200, RV200#2: 100K Lin; Potentiometer_Alpha_RD901F-40-00D_Single_Vertical

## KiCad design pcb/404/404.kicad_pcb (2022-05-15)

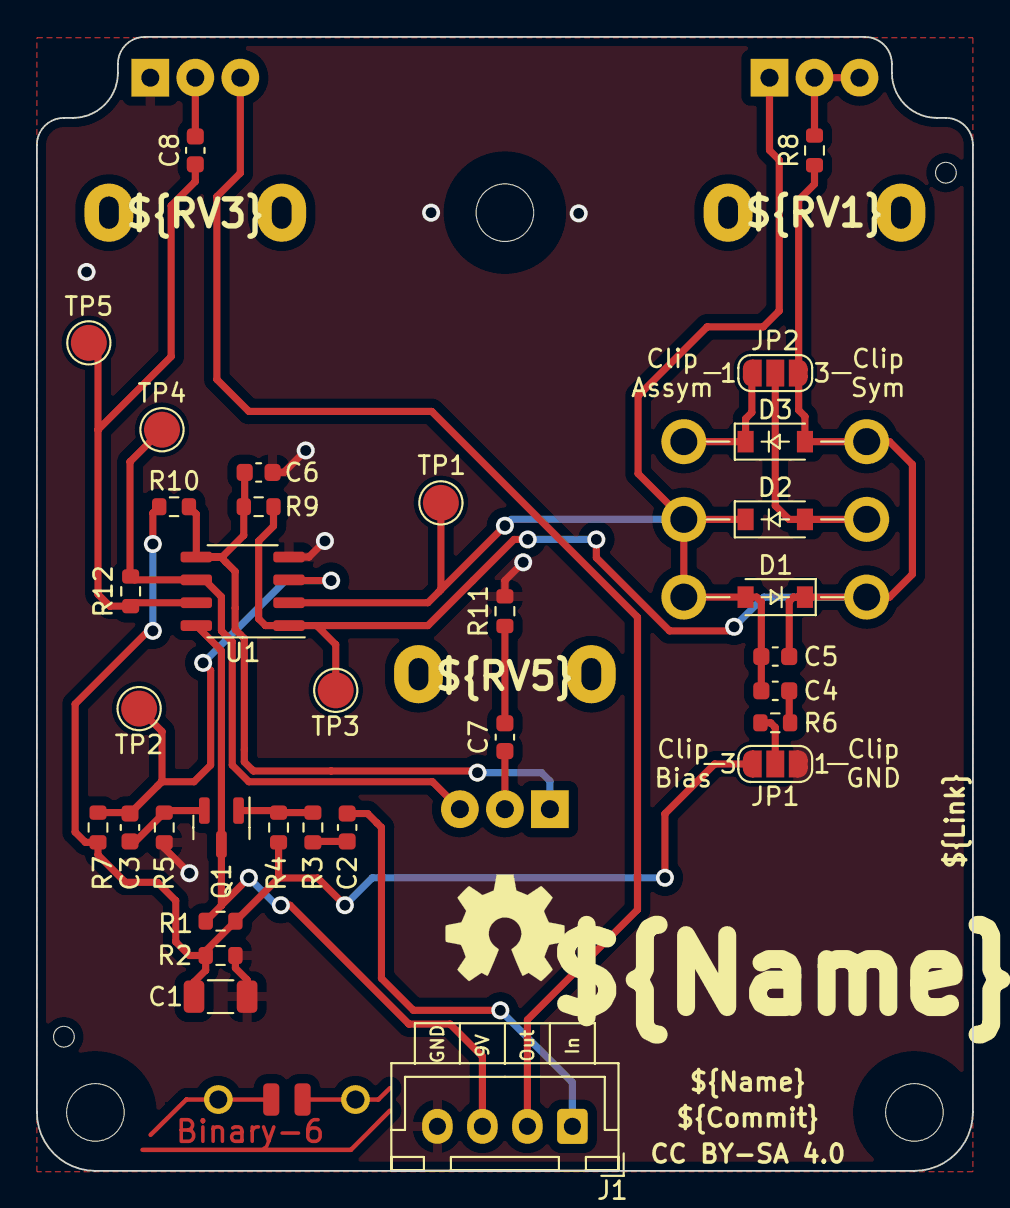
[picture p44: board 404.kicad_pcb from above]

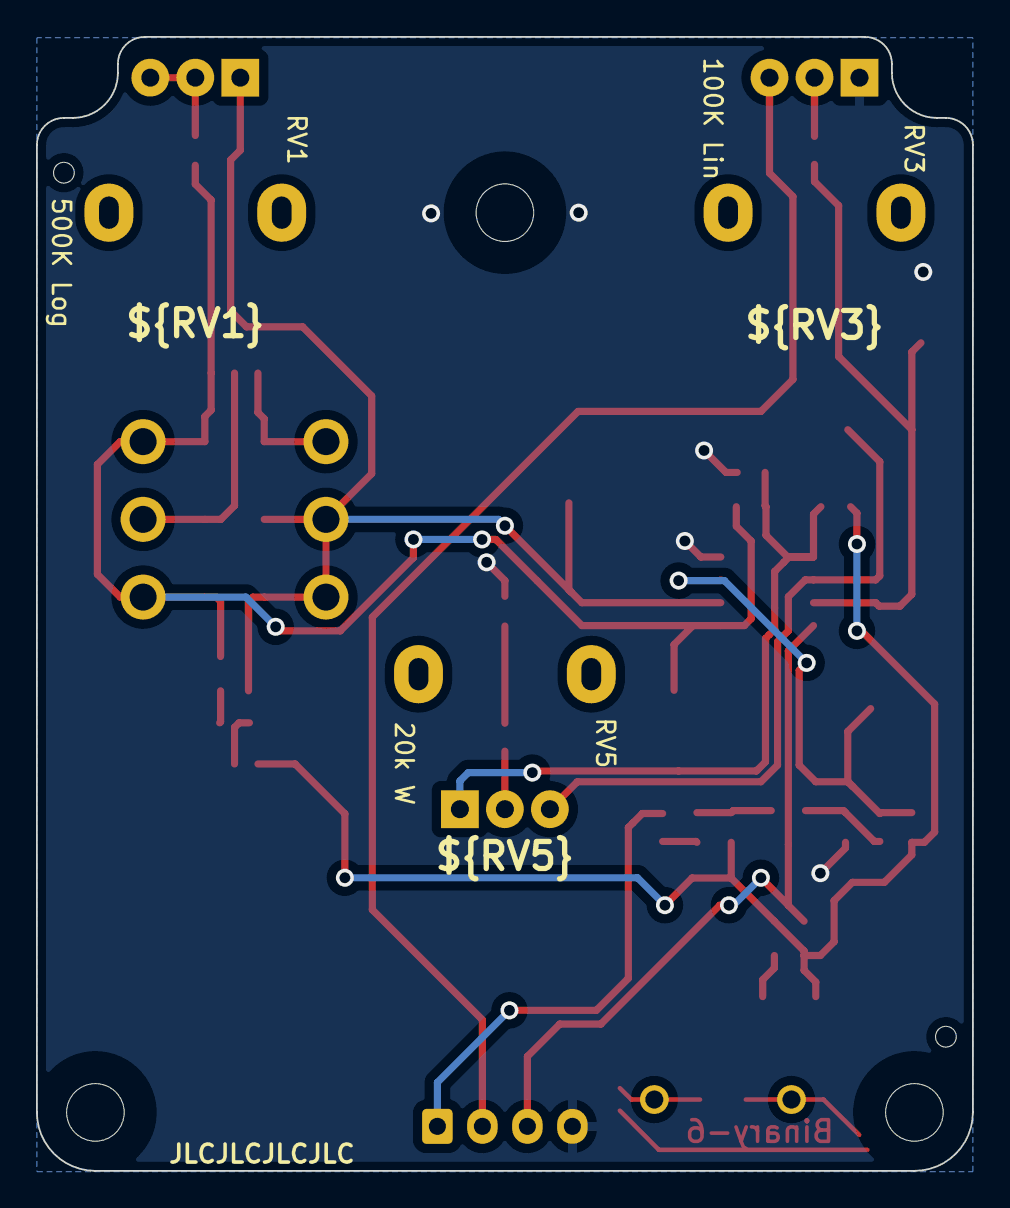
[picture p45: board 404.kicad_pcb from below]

Board: 2 copper layers, 52.0 x 63.0 mm, 40 parts (3 on the bottom side), 22 nets.

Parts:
C1: 22uF; C_1206_3216Metric
C2, C4: 47n; C_0603_1608Metric
C3, C8: 1uF; C_0603_1608Metric
C5: 47pF; C_0603_1608Metric
C6, C7: 220nF; C_0603_1608Metric
D1, D2, D3: 1N4148W; D_SOD-123+THT
H7: Symbol_Binary6; Binary_6_v0.1_tiny_silk
J1: Conn_01x04; JST_XH_B4B-XH-A_1x04_P2.50mm_Vertical
JP1, JP2: SolderJumper; SolderJumper-3_P1.3mm_Open_RoundedPad1.0x1.5mm_NumberLabels
MK2, MK2#2, MK2#3: Mounting_Hole_M3; EigenesMountingHole_3.2mm_M3_Small
Q1: BC846; SOT-23
R1, R2, R5, R7, R10: 10K; R_0603_1608Metric
R3, R9, R12: 1K; R_0603_1608Metric
R4: 510K; R_0603_1608Metric
R6: 4K7; R_0603_1608Metric
R8: 51K; R_0603_1608Metric
R11: 220R; R_0603_1608Metric
RV1: 500K Log; Potentiometer_Alpha_RD901F-40-00D_Single_Vertical
RV3: 100K Lin; Potentiometer_Alpha_RD901F-40-00D_Single_Vertical
RV5: 20k W; Potentiometer_Alpha_RD901F-40-00D_Single_Vertical
TP1, TP2, TP3, TP4, TP5: TP; TestPoint_Pad_D2.0mm
U1: RC4558; SO-8_3.9x4.9mm_P1.27mm

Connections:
+4V5: C1.1, JP1.3 (B), R1.2, R2.1, R4.1, R7.1, R10.1
+9V: J1.3, Q1.3 (C), R1.1, U1.8 (V+)
GND: C1.2, C6.2, J1.4, JP1.1 (A), R2.2, R5.2, R11.2, RV3.1, U1.4 (V-)
unnamed: C2.2, R3.1
unnamed: C3.1, Q1.2 (E), R5.1
unnamed: C3.2, R7.2, TP2.1, U1.3 (+)
unnamed: C4.1, C5.1, D1.2 (A), D2.1 (K), RV1.1, TP1.1, U1.2 (-)
unnamed: C4.2, R6.2
unnamed: C5.2, D1.1 (K), D3.2 (A), JP2.3 (B), R8.1, R9.1, TP3.1, U1.1
unnamed: C6.1, R9.2, R10.2, RV5.1, U1.5 (+)
unnamed: C7.1, RV5.2
unnamed: C7.2, R11.1
unnamed: C8.1, R12.2, TP5.1, U1.7
unnamed: C8.2, RV3.2
unnamed: D2.2 (A), JP2.2 (C)
unnamed: D3.1 (K), JP2.1 (A)
unnamed: JP1.2 (C), R6.1
unnamed: Q1.1 (B), R3.2, R4.2
unnamed: R8.2, RV1.2, RV1.3
unnamed: R12.1, RV5.3, TP4.1, U1.6 (-)
Upper_PCB_Input: C2.1, J1.1
Upper_PCB_Output: J1.2, RV3.3

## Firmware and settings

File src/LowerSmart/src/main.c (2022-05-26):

/*
 * TODO:
 * - Button debouncing
 *
 * BufferLowerSmart
 * 
 * PB0 - LED latching PWM
 * PB1 - LED momentary PWM
 * 
 * PB2 - Dry FETs
 * PB3 - Wet FETs
 * 
 * PB4 - Button Input - active LOW
 */


#include <avr/io.h>
#include <avr/interrupt.h>
#include <avr/eeprom.h>
//#include <stdint.h>
//#include <stdlib.h>


// Pins
#define LED_LATCHING    0
#define LED_MOMENTARY   1
#define FET_DRY         2
#define FET_WET         3
#define BUTTON          4


// Times
volatile unsigned long currentTime_ms   = 0;
const unsigned long holdToSwitchMode_ms = 9000;
const unsigned long blinkDuration_ms    = 100;
const unsigned long debounceDuration_ms = 100;
unsigned long lastDebounceTime_ms       = 0;
unsigned long lastButtonDownTime_ms     = 0;


// Modes
uint8_t mode                            = 0;
#define adr_mode                          0
#define mode_latching                     0
#define mode_momentary                    1


// Flags
struct {
  unsigned effectActive:1;
  unsigned modeSwitchDone:1;
  unsigned modeSwitchImminent:1;
  unsigned modeSwitchBlinker:1;
} flags;


// Inputs
struct {
  unsigned debounceInput_Button:1;
  unsigned lastDebounceInput_Button:1;
  unsigned state_Button:1;
  unsigned ftrig_Button:1;
  unsigned Last_Button:1;
} input;


// Outputs
struct {
  unsigned State_LED_Latching:1;
  unsigned State_LED_Momentary:1;
  unsigned State_FET_Dry:1;
  unsigned State_FET_Wet:1;
} output;


//Function prototypes
void init();
void readInputs();
void setOutputs();


/*******************************************************************************************/
/*****************************             ISR                     *************************/
/*******************************************************************************************/
ISR(TIM0_COMPA_vect)
{
  currentTime_ms++;
}


/*******************************************************************************************/
/*****************************             main                    *************************/
/*******************************************************************************************/
int main(){

  init();

  while(1){

    // Evaluate Inputs
    readInputs();


    // Switch between modes
    switch (mode) {
      case mode_latching:
          if (input.ftrig_Button) {
          flags.effectActive = !flags.effectActive;
        }
        break;
      
      case mode_momentary:
        flags.effectActive = !input.state_Button;
        break;
    }


    // Mode change request
    if (input.state_Button) {
      // Follow current time as long as button is not pressed
      lastButtonDownTime_ms     = currentTime_ms;
      flags.modeSwitchDone      = 0;
      flags.modeSwitchImminent  = 0;
    } else {
      // While button is pressed, wait for time elapsed
      if (((currentTime_ms - lastButtonDownTime_ms) >= holdToSwitchMode_ms) && !flags.modeSwitchDone) {
        // Switch mode if time elapsed
        if (mode == mode_momentary) {
          mode = mode_latching;
        } else if (mode == mode_latching) {
          mode = mode_momentary;
        }

        // Write mode into EEPROM
        eeprom_write_byte(adr_mode, mode);

        // Prevent cyclic toggling of mode as long as button is held
        flags.modeSwitchDone = 1;
      }
    
      // blink shortly before time is elapsed
      flags.modeSwitchImminent = ((currentTime_ms - lastButtonDownTime_ms) < holdToSwitchMode_ms) &&
                                  (currentTime_ms - lastButtonDownTime_ms >= (holdToSwitchMode_ms - blinkDuration_ms));
    }

    // Mode change blinky toggler
    flags.modeSwitchBlinker = (((currentTime_ms - lastButtonDownTime_ms) % 250) <= 125) && flags.modeSwitchImminent;


    // Evaluate Outputs
    setOutputs();

  }//end while(1)

}//end main()


/*******************************************************************************************/
/*****************************           init                *******************************/
/*******************************************************************************************/
void init() {
  //disable interrupts
  cli();

  /*  Set pinmodes
    +---+---+---+---+---+---+---+---+
    | 0 | 0 | 0 | 0 | 0 | 1 | 1 | 1 | 0 = Input, 1 = Output
    +---+---+---+---+---+---+---+---+
    | 7 | 6 | 5 | 4 | 3 | 2 | 1 | 0 | Portnumbers
    +---+---+---+---+---+---+---+---+
  */
  DDRB = 0x07; 


  // Set interrupt overflows to 1ms
  TCCR0A |= (1 << WGM01);             // set timer counter mode to CTC
  TCCR0B |= (1 << CS01);              // set prescaler to 8
  OCR0A   = 150-1;                    // set Timer's counter max value
                                      // 1.200.000 MHZ / 8 / 1000 = 150 - Overflow at 1ms
  TIMSK0 |= (1 << OCIE0A);            // enable Timer CTC interrupt
  sei();                              // enable global interrupts


  // Read in EEPROM into mode
  mode = eeprom_read_byte(adr_mode);
}


/*******************************************************************************************/
/*****************************         readInputs                  *************************/
/*******************************************************************************************/
void readInputs() {
  // Read in button
  input.debounceInput_Button = PORTB & BUTTON;


  // Debounce button
  if (input.debounceInput_Button != input.lastDebounceInput_Button) {
    lastButtonDownTime_ms = currentTime_ms;
  } else if (currentTime_ms - lastButtonDownTime_ms >= debounceDuration_ms) {
    input.state_Button    = input.debounceInput_Button;
  }


  // Evaluate edge on button
  input.ftrig_Button  = !input.state_Button && input.Last_Button;
  input.Last_Button   =  input.state_Button;
}


/*******************************************************************************************/
/*****************************         setOutputs                  *************************/
/*******************************************************************************************/
void setOutputs() {
  // Evaluate output flags
  output.State_FET_Wet        =  flags.effectActive;
  output.State_FET_Dry        = !flags.effectActive;

  output.State_LED_Latching   = (mode == mode_latching    && flags.effectActive && !flags.modeSwitchBlinker) ||
                                (mode == mode_momentary   && flags.modeSwitchBlinker);
  output.State_LED_Momentary  = (mode == mode_momentary   && flags.effectActive && !flags.modeSwitchBlinker) ||
                                (mode == mode_latching    && flags.modeSwitchBlinker);


  //Write outputs to port
  //LEDs inverted outputs
  if (output.State_LED_Latching) {
    PORTB &= ~(1 << LED_LATCHING);
  } else {
    PORTB |=  (1 << LED_LATCHING);
  }
  
  if (output.State_LED_Momentary) {
    PORTB &= ~(1 << LED_MOMENTARY);
  } else {
    PORTB |=  (1 << LED_MOMENTARY);
  }
  
  // FETs non-inverted outputs
  if (output.State_FET_Dry) {
    PORTB |=  (1 << FET_DRY);
  } else {
    PORTB &= ~(1 << FET_DRY);
  }

  if (output.State_FET_Wet) {
    PORTB |=  (1 << FET_WET);
  } else {
    PORTB &= ~(1 << FET_WET);
  }

}

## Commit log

2022-02-17 Create lower PCB schematic
    [Lower.kicad_pcb, Lower.kicad_sch]
2022-02-17 Assign Lower PCB footprints and BOM codes
    [Lower.kicad_sch]
2022-02-18 [Lower] Start adding devices to PCB
    [Lower.kicad_pcb]
2022-02-18 [Lower] Design and add more footprints
    [Lower.kicad_pcb, Lower.kicad_sch]
2022-02-18 [Lower] Start mechanical design
    [Lower.kicad_pcb]
2022-02-18 [Lower] Continue mechanical design
    [Lower.kicad_pcb]
2022-02-18 [Lower] Fix some footprints 3D models
    [Lower.kicad_pcb]
2022-02-18 [Lower] Add DRC rules and set board stackup parameters
    [Lower.kicad_pcb]
2022-02-18 [Lower] Remove 3D object from connector footprint
    [Lower.kicad_pcb]
2022-02-18 [Lower] Move mechanical parts to fit enclosure
    [Lower.kicad_pcb]
2022-02-19 [Lower] Update Anti-Pop circuit after testing
    [Lower.kicad_sch]
2022-02-19 [Lower] Fix board outline and update 3D components to scaled VRMLs
    [Lower.kicad_pcb]
2022-02-19 [Lower] Pinswap PCB-PCB connector
    [Lower.kicad_pcb, Lower.kicad_sch]
2022-02-20 [Lower] Move 3PDT 3D thingy
    [Lower.kicad_pcb]
2022-02-20 [Lower] Make PCB smaller
    [Lower.kicad_pcb]
2022-02-20 [Lower] Swap out C1 footprint / LCSC part for THT one
    [Lower.kicad_pcb, Lower.kicad_sch]
2022-02-20 [Lower] Fix LED wiring in Schematic, route whole board
    [Lower.kicad_pcb, Lower.kicad_sch]
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2022-02-20 [Lower] Push some parts around a bit
    [Lower.kicad_pcb]
2022-02-20 [Lower] Fix DRC violations
    [Lower.kicad_pcb]
2022-02-20 Add BaseRaw FreeCAD project, including Lower PCB but only simulation of upper one
    [BaseRaw.FCStd]
2022-02-20 [BaseRaw] Add mechanical parts for simulation of maximal configuration
    [BaseRaw.FCStd]
2022-02-20 [BaseRaw] Push mechanical parts around until i'm happy
    [BaseRaw.FCStd]
2022-02-21 [UpperRaw] Create raw upper PCB as a base for creating individual models
    [UpperRaw.kicad_pcb, UpperRaw.kicad_sch]
2022-02-22 [UpperRaw] swap mounting holes for M3 ones
    [UpperRaw.kicad_pcb]
2022-02-23 [Lower] Beautify silk and add logos
    [Lower.kicad_pcb]
2022-02-24 [Lower] Beautify silk - should be ready to order
    [Lower.kicad_pcb]
2022-02-24 [Lower] Update commit hash
    [Lower.kicad_pcb]
2022-02-24 [Lower] Update gerber output preferences
    [Lower.kicad_pcb]
2022-02-24 [Lower] Minor update to schematic BOM before ordering
    [Lower.kicad_sch]
2022-02-25 [Lower] Add tooling holes and repo link
    [Lower.kicad_pcb, Lower.kicad_sch]
2022-02-25 [UpperRaw] Create template with logos, tooling holes etc.
    [UpperRaw.kicad_pcb]
2022-02-25 [UppwerRaw] Update mechanically a bit before importing into case
    [UpperRaw.kicad_pcb]
2022-02-25 [BaseRaw] Import UpperRaw and Lower PCBs into case
    [BaseRaw.FCStd]
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2022-02-27 [BaseRaw] Add holes according to actual upper PCB
    [BaseRaw.FCStd]
2022-02-27 [ProtoSimple] Add simple protoboard first version
    [Proto-Simple.kicad_pcb, Proto-Simple.kicad_sch]
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2022-02-27 [ProtoAdvanced] Add advanced protoboard first version
    [Proto-Advanced.kicad_pcb, Proto-Advanced.kicad_sch]
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2022-03-05 [Screamer] Update diode footprint and start arranging stuff on PCB
    [Screamer.kicad_pcb, Screamer.kicad_sch]
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2022-03-05 [LowerBuffer] Fiddle with Schematic, looking for flip flop solutions
    [LowerBuffer.kicad_sch]
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2022-03-19 [ProtoAdvanced] Fix some Silk lines
    [Proto-Advanced.kicad_pcb]
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2022-04-24 [ProtoAdvanced] Update proto footprints with new tolerances
    [Proto-Advanced.kicad_pcb]
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2022-04-24 [All] Add LCSC part number for JST connector
    [404.kicad_sch, Proto-Advanced.kicad_sch, Proto-Simple.kicad_sch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]
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2022-04-24 [All] Find out that the upper left pot is 0,08mm off on all designs
    [404.kicad_pcb, Proto-Advanced.kicad_pcb, Proto-Simple.kicad_pcb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]
2022-04-24 [404] Recreate gerbers and pos file after last commits fix
    [404.kicad_pcb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]
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2022-04-24 Add Frontpanel to 3D simu and update other boards. UpperRaw has pads still misaligned in simu
    [BaseRaw.FCStd]
2022-04-25 [FrontRaw] Minor mask update around Binary logo and set grid origin
    [FrontRaw.kicad_pcb]
2022-04-25 [404] Create 404 frontpanel without any design yet
    [404_Frontpanel.kicad_pcb, 404_Frontpanel.kicad_sch]
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2022-04-25 [FrontRaw][404] Add a decorative bar as all I can think of for a "design"
    [404_Frontpanel.kicad_pcb, FrontRaw.kicad_pcb]
2022-04-25 [404] Change my mind on the design. Wires it is.
    [404_Frontpanel.kicad_pcb]
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2022-04-29 [UpperRaw] Figure out new pot positions for 6 pots
    [UpperRaw.kicad_pcb, UpperRaw.kicad_sch]
2022-04-30 [AllRaw] Update base templates to 6 controls design
    [FrontRaw.kicad_pcb, UpperRaw.kicad_pcb]
2022-04-30 [UpperRaw] Swap pot footprints
    [UpperRaw.kicad_pcb]
2022-04-30 [404] Recreate Upper and Front PCBs according to new base templates
    [404.kicad_pcb, 404_Frontpanel.kicad_pcb]
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2022-05-01 [ProtoSimple] Recreate PCB according to new base template
    [Proto-Simple.kicad_pcb, Proto-Simple.kicad_sch]
2022-05-01 [ProtoAdvanced] Delete for now. Recreate later from simple version
    [Proto-Advanced.kicad_pcb, Proto-Advanced.kicad_sch]
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2022-05-07 [All] Flip board to board connector on upper PCB (obstructed some silk)
    [404.kicad_pcb, 404.kicad_sch, Proto-Simple.kicad_pcb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]
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2022-05-08 [TOP] Consolidate footprints; Add bypass cap to U1
    [TOP.kicad_pcb, TOP.kicad_sch]
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2022-05-08 [TOP] Run and fix DRC
    [TOP.kicad_pcb]
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2022-05-08 [404][UpperRaw] Apply learned lessons from TOP:
    - Name on silk etc. is now a text variable
    - Optimized copypasta parts
    - Set pot footprint to my modified one
    - Rename pots ro always be RV1-6
    - Use text variables for pot names
    - Show pot values on silk
    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
    [404.kicad_pcb, 404.kicad_sch, UpperRaw.kicad_pcb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]
2022-05-08 [TOP] Forgot to save schematic after renaming testpoints
    [TOP.kicad_sch]
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2022-05-15 [TOP] Move via to not overlap with silk
    [TOP.kicad_pcb]
2022-05-15 Checkpoint before exporting all of 404 and TOP
    [404.kicad_pcb]
2022-05-15 [404] Fix frontpanel pent location
    [404_Frontpanel.kicad_pcb]
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2022-05-15 [All] Add 3D file for pointy pot knob to all upper boards
    [Proto-Simple.kicad_pcb, TOP.kicad_pcb, UpperRaw.kicad_pcb]
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2022-05-15 [LowerSmart] Add button debouncing and fix FET outputs
    [main.c]
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2022-05-20 [LowerSmart] Start schematic. Totally broken atm
    [LowerSmart.kicad_pcb, LowerSmart.kicad_sch]
2022-05-24 [LowerSmart] Fix source compile errors
    [main.c]
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2022-05-28 [3D] Lower drill tolerances on drill guide and make punch holes smaller
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2022-05-29 [TOP] Remove broken production_files
    [TOP-bottom-pos.csv, TOP-top-pos.csv]
2022-05-29 [TOP] Fix various problems of first design:
    - Some pins of TL072 swapped
    - Volume pot inverted
    - BOOST input of 7660 now only settable via jumper
    - Add option of TO-92/BF245 instead of SOT-23/BF545
    -
    [TOP.kicad_pcb, TOP.kicad_sch]
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2022-06-05 [TOP] Fix 7660 -> 7660S in schematic; Make circuit fit for simulation of input stage
    [TOP.kicad_sch, TOP_BOM.csv]
2022-06-05 Revert "[3D] Widen up drill guide punch holes a little bit"
    This reverts commit 361226d20ffdb9c8150007e3a37046b2b2a5f396.
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2022-06-08 [3D] Fix pot mounting holes flipped the wrong way
    [PedalDev_1590B.stp]
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2022-06-12 [YW] Add all devices to schematic and start wiring
    [YOU WHAT?!.kicad_sch]
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2022-06-15 [YW] Remove n. required stuff from schematic and modify to fit system
    [YOU WHAT?!.kicad_sch]
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2022-06-18 [YW] Rename project; Fix R6/R18 BOM
    [YOU WHAT.kicad_pcb, YOU WHAT.kicad_sch]
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2022-09-27 [Lower] Fix LCSC part number for AO3401A (Was SOT-23-L3 instead of SOT-23)
    [Lower.kicad_sch, Lower_BOM.csv]

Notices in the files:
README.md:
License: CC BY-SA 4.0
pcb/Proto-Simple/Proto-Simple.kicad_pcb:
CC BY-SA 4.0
